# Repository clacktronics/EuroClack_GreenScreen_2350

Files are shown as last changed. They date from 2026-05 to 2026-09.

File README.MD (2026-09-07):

# EuroClack Green Screen 2350

EuroClack Green Screen 2350 is a **programmable Eurorack synthesizer module built around the Raspberry Pi RP2350B**. It combines stereo audio input/output, control-voltage (CV) and gate interfaces, a colour display, hands-on controls, microSD storage and USB connectivity.

The module provides a general-purpose platform for developing digital instruments, audio effects, sequencers and modulation tools within a Eurorack system. Application firmware defines its musical behaviour, while the audio, CV and gate interfaces connect it to the rest of the patch. The display and physical controls support interactive visual instruments and direct parameter editing.

The included firmware demonstrates a Tempest-inspired game and a double-pendulum simulation with sound. Effects processing, sampling and sequencing require their own application firmware.

## Main functions

| Function | Circuit | Purpose |
|---|---|---|
| Processing | U1, RP2350B in an 80-pin package | Runs the application, processes audio and CV, generates gates and manages the interface. |
| Program storage | U4, W25Q128JVS | External 128-Mbit / 16-MiB flash for firmware and stored data. |
| Additional memory provision | U15, labelled `SRAM` | Shares the QSPI data/clock bus with a separate chip select. The actual memory part and capacity are unspecified. |
| Two audio inputs | U6 TL072 stages and U5 PCM1808 | Condition analog signals and convert them to digital audio for the processor over I²S. |
| Two audio outputs | U2 PCM5102 and output filters | Convert the processor's I²S stream into left/right analog audio. |
| Four CV inputs | U13/U20 amplifier stages and MCU ADC inputs | Scale and offset external control voltages for measurement by the processor. |
| Four gate-sensing paths | U19/U21 LM393 comparators | Detect gate/trigger levels: two share CV inputs and two use dedicated gate jacks. |
| Four CV outputs | U3 MCP4728 and U8/U17 amplifier stages | Convert four digitally programmed values into analog control voltages. |
| Two gate outputs | U18/U22 SN74LVC1T45 | Translate processor logic into nominal 0/5-V gate signals through series output resistors. |
| Display and controls | SPI display connections, two push encoders and buttons | Provide graphical feedback, parameter editing and navigation. |
| Storage and expansion | microSD, external I²C, USB-C device and USB-A host connections | Provide hardware paths for files, peripherals and computer/device communication, subject to firmware support. |

There are **six physical CV/gate input jacks**: two CV-only, two shared CV/gate and two gate-only. The shared inputs are measured by both an ADC path and a comparator path, allowing firmware to read a control voltage and detect gate transitions from the same connection.

## How signals move through the circuit

```text
Audio inputs --> analog conditioning --> PCM1808 ADC --I²S--> RP2350B
Audio outputs <-- output filters <----- PCM5102 DAC <--I²S-- RP2350B

CV inputs ----> scaling and offset -----------------------> MCU ADCs
Gate inputs --> comparator thresholds -------------------> MCU GPIO
CV outputs <--- amplifier stages <----- MCP4728 DAC <------ MCU control
Gate outputs <- 3.3-V to 5-V translation <----------------- MCU GPIO

                     RP2350B
                        |
         Display / encoders / buttons / microSD / USB / I²C
```

The audio converters handle continuous sampled sound. The separate CV DAC and gate circuitry let firmware interact with other modular instruments: reading modulation, following clock or trigger events, and generating control signals. The analog stages adapt these signals to the processor and converters; their resistor ratios and reference voltages determine the actual voltage ranges.

## Display, controls and example firmware

The supplied sketches target an **NV3030B colour TFT at 280 × 240 pixels in landscape orientation**. The schematic provides parallel eight-pin header and FFC display connections; the fitted panel must match the driver and pinout.

- [Tempest demo](demo_scripts/nv3030b_tempest/nv3030b_tempest.ino): an encoder-controlled arcade-style game with audio output.
- [Double-pendulum demo](demo_scripts/nv3030b_pendulum/nv3030b_pendulum.ino): a visual physics simulation whose second pendulum's X/Y position drives the left/right audio channels.

The sketches demonstrate display rendering, encoder input and audio generation. USB MIDI, sample playback, sequencing and effects require additional application firmware. See [PERIPHERALS.md](PERIPHERALS.md) for GPIO assignments, converter configuration and firmware considerations.

## Power and physical construction

Power enters through the ten-pin Eurorack connector J18 using +12 V, ground and −12 V. The design includes MOSFET protection circuitry, switching and linear regulators for its intended 5-V and 3.3-V rails, and a 3.3-V reference with an inverted reference for CV conditioning. The analog amplifier stages use the bipolar rails. USB-C VBUS is unconnected, so this design is intended to be self-powered rather than powered from a computer's USB port.

The PCB contains processor, jack/control and SD-extension sections. A 40-way FFC links the processor and jack sections, carrying signals and power; separate connections serve the SD extension. Cable orientation and pin mapping are documented in [PERIPHERALS.md](PERIPHERALS.md).

## Current development status

This is a prototype design with documented electrical issues. The existing [DESIGN_REVIEW.md](DESIGN_REVIEW.md) reports power-supply faults, input-protection gaps, audio coupling/mute issues and incorrect CV output scaling. In particular, **the intended ±5-V CV range is not an established working capability**: the review calculates approximately 0–1.65 V for the current CV output stage. Read that review before assembly or power-up.

This README documents the module's architecture and application scope. Electrical findings and validation limits are recorded in the design review.

## Project files

- `EuroClack - Green_Screen_2350.kicad_pro` — open this project in KiCad.
- `EuroClack - Green_Screen_2350.kicad_sch` — current circuit schematic.
- `EuroClack - Green_Screen_2350.kicad_pcb` — PCB layout.
- [libraries/README.md](libraries/README.md) — bundled custom libraries and dependencies. The schematic uses KiCad 10 format; the PCB uses KiCad 9 format.
- [PERIPHERALS.md](PERIPHERALS.md) — detailed connections and firmware reference.
- [DESIGN_REVIEW.md](DESIGN_REVIEW.md) — existing engineering review and limitations.
- `demo_scripts/` — example display, controls and audio sketches.

The root PDF represents an older RP2040 design; use the native RP2350 KiCad schematic as the source for this revision.

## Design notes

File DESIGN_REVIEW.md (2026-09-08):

# EuroClack Green Screen 2350 — design review

Reviewed **8 September 2026**, using KiCad **10.0.6**, against the saved schematic, PCB and project settings. **Not ready for fabrication or power-up.** Five previous findings have been corrected in the schematic, but those changes have not reached the PCB. Six other finding groups remain open.

This report replaces the 7 September review. Corrected schematic complaints have been removed from the active issue list. Their implementation status is recorded below so they cannot disappear prematurely from the fabrication checklist. Design files were not edited. The previous report is preserved in [DESIGN_REVIEW.previous.md](analysis/2026-09-08_1152/DESIGN_REVIEW.previous.md).

## Changes since the previous review

| Previous finding | Current schematic evidence | Status |
|---|---|---|
| U12/U23 EN overstress | Both pin 5 EN inputs now have individual unconnected nets. TPS54302 explicitly permits floating EN. | Corrected in schematic; old 12 V connection remains on PCB |
| R4 disconnects +5 V; U12 divider gives 3.934 V | R4 removed; L2 output and R91 connect directly to +5V. R91=75k, R92=10k gives `0.596 × 8.5 = 5.066 V`. | Original fault corrected in schematic; old R4 and 56k remain on PCB |
| C9/C10 short audio input coupling | Both are now 1 µF capacitors. | Corrected in schematic; PCB values remain 0R |
| CV outputs cannot reach ±5 V | DAC-input resistors are 1.96k; negative-reference resistors 6.49k; feedback 10k. Forty current-value DC simulations agree with calculation. | Corrected nominal schematic transfer; eight PCB resistor values remain 20k |
| U2 XSMT floating | Pin 17 now connects to +3.3V, the same rail as DVDD. | Corrected in schematic; PCB still has isolated mute net |

Evidence: [current native connection inventory](analysis/2026-09-08_1152/component_connections.txt), [connectivity audit](analysis/2026-09-08_1152/connectivity_audit.json), [schematic delta](analysis/2026-09-08_1152/schematic_diff.json), and [review delta](analysis/2026-09-08_1152/review_delta.json). Floating EN is supported by [TPS54302, PDF p3](datasheets/TPS54302.pdf). The 5.066 V result resolves the old gross setpoint error; component tolerance and the required rail accuracy still need budgeting.

D3/D4 have also been added to the dedicated gate inputs. That is an attempted protection improvement, not a closed finding: see the comparator section. Library aliases have largely moved to the project-local EuroClack library. The PCB analyzer's tracked geometry/component comparison reports no changes from the prior PCB analysis; this is not a byte-for-byte equality claim.

## Active findings

| Priority | Finding | Evidence / confidence |
|---|---|---|
| Critical | PCB still implements the old supply, mute and component values; D3/D4 are missing | High: native parity and complete common-pin comparison |
| Critical | U13/U20 can overdrive the RP2350 ADC inputs | High: unchanged native nets, manufacturer limits and current DC simulation |
| Critical | U19 remains exposed to negative CV; U21 clamp current is uncontrolled | High connectivity confidence; clamp behavior depends on patch source and diode current |
| Critical | J20 reverses standard STEMMA QT power/signal order | High: native pad mapping and official connector specification |
| Critical, conditional | Q1–Q4 mapping conflicts with AO3400A/AO3401A if those are the intended parts | High conditional confidence; exact identities unresolved |
| Functional | DAC SCL/SDA are swapped relative to RP2350 hardware I2C1 | High: native nets and GPIO function definitions |
| Assembly / startup | TL072 MSOP ordering code and U15 memory remain unspecified; R3 is DNP | High documentation/population confidence; actual part compatibility unresolved |

### 1. Synchronize and route the PCB before release

The fresh DRC found **0 geometry errors, 28 warnings and 0 unconnected items**, but also **234 schematic parity issues**. Zero unrouted connections only describes the PCB's existing net assignments; it does not mean it implements the current schematic.

The following are substantive differences:

- U12.5 remains tied to +12V and U23.5 to /12V_JACK in the PCB, despite the schematic floating-enable correction. The old copper exceeds the TPS54302 EN absolute maximum of 7 V. [TPS54302, PDF pp3–4](datasheets/TPS54302.pdf)
- R4 remains a DNP 0 Ω footprint between L2 and the main +5V/output-capacitor bank. The current schematic has removed it and joined that path. Do not remove its footprint without restoring the copper connection.
- R91 remains 56k on the PCB versus 75k in the schematic. C9/C10 remain 0R versus 1u. R17/R36/R39/R42 remain 20k versus 1.96k; R13/R26/R37/R40 remain 20k versus 6.49k. These **11 value mismatches** can propagate incorrect assembly values.
- U2.17 remains on the old isolated /I2S_DAC_MUTE net instead of +3.3V.
- D3/D4 and all six pads are absent from the PCB. Their circuit also needs the protection corrections below before layout.

Native parity categorizes the 234 items as 199 field mismatches, 13 symbol/footprint mismatches, 19 net conflicts, two missing footprints and one extra footprint. Many field differences concern datasheet metadata. The 13 symbol/footprint mismatches comprise the eleven values above and two JP1/JP2 BOM-attribute differences. Five renamed nets have equivalent connected-pin sets and are not electrical opens.

Update the PCB from the corrected schematic, inspect the affected copper and population data, then rerun parity and DRC. Merely accepting renamed nets or reducing the warning count does not resolve the old EN tracks or R4 supply break. [DRC/parity report](analysis/2026-09-08_1152/drc.json)

### 2. MCU ADC input protection and range remain unresolved

U13 outputs 1/7 and U20 outputs 1/7 still directly drive U1 ADC pins 49/52/53/54. All four amplifiers run on ±12 V; there is no output-side limiting/clamping network. The input resistors are before the amplifiers and cannot protect the MCU from their output voltage.

The unchanged nominal transfer is `VADC = 1.60147 − 0.33 × VCV`:

| External CV | Nominal ADC voltage |
|---:|---:|
| −12 V | 5.561 V |
| −5 V | 3.251 V |
| 0 V | 1.601 V |
| +5 V | −0.049 V |
| +12 V | −2.359 V |

The ±12 V cases exceed the standard ADC GPIO absolute limits, −0.5 V to IOVDD+0.5 V. The +5 V case is outside the normal unipolar measurement range even though −0.049 V alone is not an absolute-maximum violation. Revise scale/offset with tolerance headroom and design output-side current limiting and clamping; include unpowered behavior and ADC settling. **High confidence: native topology, manufacturer electrical limits, and ideal DC checks.** [RP2350, electrical characteristics](datasheets/RP2350.pdf)

### 3. Comparator input protection is only partially addressed

U19 pins 3/5 still connect to the hybrid CV/gate signals through FB12/FB5. R45/R48 are on the parallel amplifier branches, not in series with the comparator inputs. Normal negative CV can therefore drive the ground-powered LM393 inputs below their −0.3 V limit. This previous finding remains unchanged for U19. [LM393, §5.1 and input-range notes](datasheets/LM393.pdf)

D4 now connects U21 pin 3 and D3 connects U21 pin 5 to dual clamps between GND and +5V. Their orientation is consistent with the BAT54SW series-diode pinout. However, the path from each dedicated gate input through the interconnect to its clamp has **no board-side series current-limiting resistor**. R95/R96 are 1 MΩ shunts, not series limiters. Clamp current therefore depends on the external source impedance; positive overvoltage also injects into +5V. A clamp is not a safe substitute for controlling that current and checking the receiving rail's ability to absorb it.

BAT54SW's forward-voltage maximum is 320 mV at 1 mA and rises at higher current, so its presence alone does not establish the LM393's −0.3 V input limit. Add a calculated series/protection arrangement on each comparator branch and evaluate clamp current, negative input behavior and powered/unpowered rails. Avoid clamping the shared bipolar measurement signal before the CV amplifier branch. D3/D4 are also absent from the PCB. **High confidence in missing current limiting; actual stress depends on the connected source.** [BAT54SW, pinning and electrical characteristics](datasheets/BAT54SW.pdf)

Comparator outputs still have no external pull-ups. Firmware pull-ups may provide operation; document startup state and rise-time requirements. Thresholds remain approximately 1.091 V and explicit hysteresis was not found.

### 4. J20 still has the wrong STEMMA QT pin order

| Pad | Current schematic and PCB | STEMMA QT SH convention |
|---|---|---|
| 1 | SCL | GND |
| 2 | SDA | V+ |
| 3 | +3.3V | SDA |
| 4 | GND | SCL |

Correct the pad mapping and verify the mating cable orientation before connecting a standard device. This finding is unchanged. **High confidence: raw/native mapping and the manufacturer's interface documentation.** [Adafruit technical specifications](https://learn.adafruit.com/introducing-adafruit-stemma-qt/technical-specs)

### 5. MOSFET identity and pin mapping remain conditional blockers

Q1/Q4 are still labelled A3400A and Q2/Q3 A3401A without explicit manufacturer MPNs. Their symbols assign 1=gate, 2=drain, 3=source. Candidate AO3400A/AO3401A parts instead use 1=gate, 2=source, 3=drain. If these are intended, the body-diode and switching topology is wrong. Resolve identity and symbol-to-pad mapping before assembly. Q1's nominal 12 V gate-source operation would also leave no margin against AO3400A's ±12 V gate rating. **High confidence conditional on the intended part.** [AO3400A, p1](datasheets/AO3400A.pdf), [AO3401A, p1](datasheets/AO3401A.pdf)

### 6. DAC hardware I²C mapping is still swapped

U1 GPIO22 goes to U3 SCL and GPIO23 to U3 SDA. RP2350's hardware I2C1 function uses GPIO22=SDA and GPIO23=SCL. Swap the connections for hardware I²C, or document and implement a software/PIO bus. The DAC's own symbol pin names are correct. **High confidence: native connectivity and GPIO function definitions.** [RP2350, GPIO22_CTRL/GPIO23_CTRL](datasheets/RP2350.pdf)

### 7. Assembly identity and boot bias remain unresolved

U6/U8/U11/U13/U17/U20 still use generic TL072 values with MSOP-8 3×3 mm footprints. The saved TI family datasheet does not establish a matching ordering code for this footprint. Specify a compatible part/package or change footprints. ±12 V operation itself is not the fault. U15 remains generic SRAM with no exact device to establish its command, voltage and package compatibility. [TL072, package information](datasheets/TL072.pdf)

R3 remains DNP in both schematic and PCB. Restore or justify the flash-CS startup bias against the [RP2350 hardware guide, flash interface](datasheets/RP2350-hardware.pdf). R22 provides a populated pull-up for the second memory. Exact passive ratings, F1 hold/trip current, connector mating and procurement suffixes remain assembly gaps; recognizable value strings do not constitute full MPN coverage.

## Power tree and analog status

| Source | Conversion / consumers | Current assessment |
|---|---|---|
| Eurorack ±12 V | Q1/Q2; six dual amplifier packages | Resolve conditional FET mapping and gate stress |
| +12 V | U12/L2 → +5V | Schematic 5.066 V nominal, direct output path and floating EN; PCB stale |
| +5 V | U14 → +3.3V MCU/digital rail | Budget total current and thermal rise |
| +12 V | U9 → +3.3VA; U16 → /3V3_DAC | Large LDO voltage drop remains |
| +12 V | U10 → +5VA audio ADC | Budget dissipation and loads |
| +5 V | U7 → 3.3 V reference; U11 → −3.3 V | Defines ADC/CV offset accuracy and startup behavior |
| /12V_JACK | U23 → /3V3_SD_SCREEN | 3.305 V nominal; schematic EN corrected, PCB stale |
| MCU 3.3 V | Internal regulator / L3 → +1V1 | Full dynamic load/inrush budget not established |

U12's output-capacitor bank is connected directly in the schematic after the R4 removal; that connection is the supply-path correction, not evidence of converter stability. U23's 100k/22k divider remains nominally correct. Both divider calculations were rerun through ideal DC servo simulations.

The corrected CV summer gives `Vjack = 5.084745763 − 0.002551020408 × code` with MCP4728 internal 2.048 V reference, gain ×1 and normal mode. Codes 33/1993/3953 give approximately +5.000562/+0.000562/−4.999438 V. Firmware must apply those DAC settings, restrict requested CV to ±5 V, and calibrate each channel. The schematic note calls for 0.1% resistor networks. This is a nominal transfer correction, not a measured precision or capacitive-load stability result. [MCP4728, reference selection](datasheets/MCP4728.pdf)

C9/C10 now restore AC isolation into the PCM1808 input network. The former 0 Ω bias-short complaint is removed for the schematic. Validate effective capacitance, low-frequency response and maximum audio input amplitude during bring-up. U2's XSMT is now high in the schematic. [PCM1808, §8.2.2.4](datasheets/PCM1808.pdf), [PCM5102, XSMT pin function](datasheets/PCM5102.pdf)

## Component and connectivity verification

Raw-file counting finds **272 non-power symbol instances, 256 physical references and 273 PCB footprints**, including mechanical/depanelization items. The native netlist contains 256 components. The inventory covers every native component's reference, value, footprint, pin function and net. All **901 common connected schematic/PCB pins** were compared, with 242 equivalent net groups; the substantive differences are listed above. D3/D4 account for six schematic pins absent from the PCB. Separate intentional NC USB VBUS pads explain another grouping difference.

The analyzer reports 94 capacitors, 73 resistors, 23 ICs, 31 connectors, four MOSFETs, four diodes, six switches, two jumpers, sixteen ferrite-category parts, and one each of crystal, other inductor and fuse. Treat this as a classification summary: the native inventory is authoritative. For example, R3 is DNP but the analyzer's summary DNP count omits it; direct inspection finds R3/R101/R102 DNP in the schematic, plus R4 on the old PCB.

Manual manufacturer-family checks and cached PDF evidence support the electrical findings above. They do not establish exact selected-part compatibility for every component. The current inventory and saved PDFs allow repeat checks, but no complete structured extraction cache or per-MPN verification coverage is claimed. The previous `analysis/deep_review.json` describes the old design and is historical only; the current [review_delta.json](analysis/2026-09-08_1152/review_delta.json) supersedes its stale supply, mute, coupling and CV-output conclusions.

## PCB, EMC and manufacturing

The panel remains approximately **109.2×110 mm, four copper layers**, with 3330 track segments, 393 vias and 14 zones. The project now permits 0.09 mm minimum track width, 0.1 mm clearance and 0.05 mm via annular width. The previous small-via concern remains: 392 vias use 0.25 mm pads and 0.15 mm drills, nominally 0.05 mm annular rings. Obtain fabricator acceptance for the actual stackup/process before release; none is specified here.

DRC with in-memory zone refill found 6 silk-edge-clearance, 4 silk-over-copper, 17 silk-overlap warnings and one dangling track. Resolve the QSPI-clock stub and artwork issues. Several checks, including library footprint matching and missing courtyards, are configured as ignored: fewer warnings do not demonstrate that every formerly reported library issue was fixed.

EMC analysis reran with **147 heuristic findings across eight checked categories**. Its aggregate score is not a compliance result. The meaningful retained risks are the jack-section reference geometry, mixed-signal interconnect returns, connector-side ESD protection and clock transitions. J21/J22 still allocate only pin 18 explicitly to ground in each 40-pin interconnect. The MCU/SD sections have inner ground zones, while the jack section relies on outer-layer ground zones. Whole-panel plane-gap estimates can overstate individual signal problems; assess actual return paths per section.

USB routed-length totals retain the previous approximate mismatches of 0.258 mm for the device link and 0.885 mm for the host link. These are trace totals, not a validated 90 Ω differential channel including FFC and packages. Connector-side USB TVS protection was not found. U1 has nine embedded plated thermal holes; do not repeat a missing-thermal-vias heuristic for it. Fiducials were not identified; provide them if required for automated assembly.

The self-powered USB-C implementation leaves VBUS unconnected and has separate 5.1k CC resistors. Firmware attach/VBUS behavior, PIO-host termination and permitted host load remain to be validated. Identify access to protected rails, +1V1, references, SWD/RUN, I²C and audio clocks for bring-up.

## Thermal and simulation results

The thermal analyzer ran but assessed **zero components** and returned SKIPPED. It is not a thermal pass. The previous first-order SPX3819 model remains applicable: 191 °C/W, 40 °C ambient, 125 °C junction ceiling, ignoring ground current. This gives approximate current ceilings of 51 mA for 12→3.3 V and 64 mA for 12→5 V. At the new 5.066 V main rail, the same model gives about 252 mA for U14's 3.3 V output. These are conditional thermal bounds, not approved load ratings. U16 at 32 mA estimates about 93 °C junction; U10 at 11 mA about 55 °C. Establish actual loads, ambient and copper cooling. [SPX3819, PDF p2](datasheets/SPX3819.pdf)

The standard SPICE runner could not find an executable simulator. The existing KiCad ngspice shared-library method was adapted to current values: **40 CV-output channel/load cases plus nine targeted DC cases passed numerical agreement checks**. These tests validate calculations, including the still-unsafe ADC transfer; they do not validate real op-amp limits, transients, regulator stability, thermal operation or damage tolerance. Scripts and results are saved in this run's [CV output checks](analysis/2026-09-08_1152/cv_output_spice/results.json) and [targeted checks](analysis/2026-09-08_1152/spice_targeted/results.json).

## Native checks, false positives and reviewer overrides

| Check | Current result |
|---|---|
| Schematic analyzer | Rerun; 171 findings before manual triage |
| PCB analyzer | Rerun with --full; compared with prior output |
| Cross-domain analyzer | Rerun; 17 findings, including the value/missing-part mismatches |
| KiCad ERC | 1 error, 65 warnings |
| KiCad DRC with parity and refill | 0 geometry errors, 28 warnings, 0 unconnected items, 234 parity items |
| Independent native connectivity | Complete common-pin comparison and missing-pad audit |
| EMC / thermal | Both rerun; heuristic EMC risks / zero thermal assessments |
| SPICE | Standard runner unavailable; 49 shared-library ideal DC checks completed |
| Prior-review delta | Schematic/PCB JSON comparison and manual reconciliation of all 11 prior finding groups |

The ERC error is **#FLG03 connected to #FLG05**, two PWR_FLAG annotations on a common net. Remove the redundant flag; it does not prove physical source contention. Warnings include off-grid endpoints, library-symbol differences, dangling wires/NC markers and alias labels. The retained I2S_DAC_MUTE label now aliases +3.3V and I2S_DAC_SCK aliases GND; clean up misleading labels as appropriate. [ERC report](analysis/2026-09-08_1152/erc.json)

Other overrides retained after checking current nets:

- The analyzer still splits GND_JACK incorrectly. Use the native netlist for ground connectivity conclusions.
- RP2350's 1.1 V core is not its GPIO voltage domain; automated 1.1 V/3.3 V interface warnings are not evidence that all digital buses need level shifters. The ADC overdrive finding instead follows the actual amplifier transfer and GPIO limits.
- REF3033 supplies ADC_AVDD through /VREF_ADC; the automated claim of no DC supply path is not accepted.
- Grounded PCM5102 SCK supports PLL/three-wire operation. PCM1808 mode pins have internal pulldowns, and U11's unused half is a terminated follower.
- Five net renamings have identical common-pin sets. J19/J28 connector-only ground heuristics require the separate power/ground connections to be considered.
- Heuristic EMC plane gaps and missing-filter lists are risks to inspect, not a count of proven emissions failures.

## Review limits and release conditions

No Gerber/drill outputs were present, so fabrication-output analysis was not applicable. No fabricator was selected. Lifecycle audit was not run because full MPN coverage is absent; the prior PCM5102 lifecycle observation was not freshly rechecked and is not presented as a current status claim. Existing PDFs and cached text support family-level checks; complete selected-part pin/package/rating verification remains unavailable for unspecified parts, especially U15 and Q1–Q4.

Not performed: switching-loop/stability, inrush, startup and fault-current simulation; full noise/THD/anti-alias/ADC-settling validation; worst-case tolerance verification; complete load budget; firmware build or memory/USB validation; measured thermal/EMC/ESD tests; new rendered schematic/layout visual review. In-memory refill was used for DRC without saving the board; analyzer copper geometry uses the saved fills.

**Release remains blocked by the stale PCB and the active electrical/assembly findings.** Correct the remaining schematic issues, synchronize and route the PCB, then rerun parity, ERC/DRC and the affected electrical checks. The five corrected schematic findings above should not be reopened as design mistakes; their remaining work is implementation in the PCB and validation of the stated operating assumptions.

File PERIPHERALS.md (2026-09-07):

# EuroClack Green Screen 2350 — peripheral / firmware reference

Basis: current RP2350 schematic and PCB, 7 September 2026. **GP numbers are MCU GPIO numbers; `U1.n` means physical QFN-80 pad n.** This is the RP2350B / 48-GPIO design, not the RP2040 design in the older root PDF. All I²C addresses below are **7-bit**. Logic is nominally 3.3 V unless stated otherwise.

Evidence: [native component connections](analysis/component_connections.txt), PCB comparison and matching [source hashes](analysis/manifest.json); linked datasheets for protocols; existing demo for the display. Pin mappings have high connectivity confidence; analog formulas are nominal calculations. Panel settings and unidentified memory remain conditional. Firmware operation has not been tested.

## Before bring-up

Resolve the power and input-protection faults in [DESIGN_REVIEW.md](DESIGN_REVIEW.md) before operating this revision: U12/U23 EN overstress; DNP R4 and the incorrect main +5 V divider; candidate MOSFET pinout mismatches; unprotected bipolar CV/comparator inputs. Audio input coupling, DAC mute and CV output scaling also need the corrections described below. Firmware cannot repair these electrical faults.

Power enters **J18: 1–2 = −12 V, 3–8 = GND, 9–10 = +12 V**, through Q1/Q2. Intended rails: U12 → +5 V; U14 → digital +3.3 V; U9 → +3.3VA for CV DAC; U10 → +5VA for audio ADC; U16 → 3V3_DAC for audio DAC; U23 → 3V3_SD_SCREEN on jack board. U7 supplies the 3.3 V ADC reference; U11 generates −3.3 V for CV offsets. These supplies have no software address or MCU enable. Y1 is annotated **12 MHz**; match the clock configuration to the fitted crystal.

## MCU pin allocation

| Peripheral / signal | GPIO → U1 physical pad | Interface / direction at MCU |
|---|---|---|
| External I²C SDA, SCL | GP4 → 1; GP5 → 2 | Hardware **I2C0**, open drain |
| CV DAC SCL, SDA | GP22 → 22; GP23 → 23 | **Software/PIO I²C** as wired |
| Audio DAC BCK, LRCK, DIN | GP6 → 3; GP7 → 4; GP8 → 6 | PIO I²S, all outputs |
| Audio ADC BCK, LRCK, DOUT | GP9 → 7; GP10 → 8; GP11 → 9 | PIO I²S: clocks out, data in |
| Audio ADC SCKI / MCLK | GP21 → 21 | CLOCK_GPOUT0 or suitable PIO clock |
| Display DC, CS, SCK, MOSI | GP12 → 11; GP13 → 12; GP14 → 13; GP15 → 14 | GPIO DC/CS; **SPI1** clock/TX |
| Display RESET, backlight | GP16 → 16; GP17 → 17 | GPIO reset; GPIO/PWM backlight |
| Gate outputs 1, 2 | GP18 → 18; GP19 → 19 | Digital outputs, active high |
| USB host D−, D+ | GP1 → 78; GP2 → 79 | PIO USB |
| USB host power control | GP24 → 25 | GPIO; intended **high = on** |
| MENU / BOOT, USER1, USER2 | GP25 → 26; GP26 → 27; GP27 → 28 | Inputs, pull-ups, active low |
| Encoder 1 switch, A, B | GP28 → 36; GP29 → 37; GP30 → 38 | Inputs with pull-ups |
| Encoder 2 switch, A, B | GP31 → 39; GP32 → 40; GP33 → 42 | Inputs with pull-ups |
| SD CLK, CMD/MOSI, DAT0/MISO | GP34 → 43; GP35 → 44; GP36 → 45 | **SPI0**, or PIO SDIO |
| SD DAT1, DAT2, DAT3/CS | GP37 → 46; GP38 → 47; GP39 → 48 | SDIO data; GP39 GPIO CS in SPI mode |
| CV inputs 1–4 | GP40 → 49; GP41 → 52; GP42 → 53; GP43 → 54 | ADC channels **0, 1, 2, 3** |
| Gate inputs 1–4 | GP44 → 55; GP45 → 56; GP46 → 57; GP47 → 58 | Digital inputs with pull-ups |
| Second QSPI memory CS | GP0 → 77 | QMI CS1n, active low |
| USB device D−, D+ | Dedicated pads 66, 67 | Native USB controller; no GP number |
| SWCLK, SWDIO, RUN | Dedicated pads 33, 34, 35 | Debug / reset; RUN active low |
| Unconnected GPIOs | GP3 → 80; GP20 → 20 | No peripheral / connector assigned |

Use an RP2350B board configuration supporting GPIOs 0–47 and its ADC mapping; do not inherit Pico 2's physical pin map, GP25 LED assumption, or 4 MiB flash size. Hardware function assignments: [RP2350 §1.2](https://datasheets.raspberrypi.com/rp2350/rp2350-datasheet.pdf).

## CV DAC — U3 MCP4728, four outputs

- **Address:** normally `0x60`; probe `0x60–0x67` for a reprogrammed/factory-selected address. At `0x60`, wire address bytes are `0xC0` write / `0xC1` read. Commands replace a numbered-register map.
- **Bus:** GP22 → U3.2 SCL; GP23 → U3.3 SDA. R105/R106 provide 10 kΩ pull-ups. Start at 100 kHz, drive low/release high and check ACKs. Hardware I2C1 would require GP22=SDA, GP23=SCL: use software/PIO or physically swap the nets.
- **Startup:** explicitly select normal operation (`PD=00`), VDD reference (`VREF=0`), gain 1. For `ch=0..3` and 12-bit `code`, send volatile Multi-Write payload `[0x40 | (ch << 1), (code >> 8) & 0x0F, code & 0xFF]`.
- **Updates:** Fast Write sends `[(code >> 8) & 0x0F, code & 0xFF]` per channel, A→D. LDAC (U3.4) is grounded: ordinary writes update sequentially. RDY/BUSY (U3.5) is NC. Use volatile writes for CV; reserve EEPROM writes for startup presets. Reprogramming the address requires unavailable LDAC transitions. [MCP4728 §§5.3–5.6](https://ww1.microchip.com/downloads/en/DeviceDoc/22187E.pdf)

| DAC channel | U3 output | Analog stage | Front-panel output |
|---|---|---|---|
| A / 0 | Pin 6 | U8A | CV1, J7 tip |
| B / 1 | Pin 7 | U8B | CV2, J8 tip |
| C / 2 | Pin 8 | U17A | CV3, J9 tip |
| D / 3 | Pin 9 | U17B | CV4, J10 tip |

**Actual nominal transfer:** `Vout = 1.65 − 0.5 × Vdac`; with VDD=3.3 V, `Vdac ≈ 3.3 × code/4096`. Increasing code decreases jack voltage. Code 0 gives about +1.65 V; 4095 gives about +0.0004 V. The present circuit cannot produce its intended ±5 V range. Internal-reference gain 2 cannot yield 4.096 V from a 3.3 V supply. Recalculate and calibrate this mapping after correcting the analog stage.

## CV inputs and gate inputs

| Front-panel input | Analog path | ADC channel / GPIO | Comparator path / GPIO |
|---|---|---|---|
| CV1, J3 tip | U13A output 1 | ADC0 / GP40 | None |
| CV2, J4 tip | U13B output 7 | ADC1 / GP41 | None |
| CV/Gate3, J5 tip | U20A output 1 | ADC2 / GP42 | U19.1 → GP46 |
| CV/Gate4, J13 tip | U20B output 7 | ADC3 / GP43 | U19.7 → GP47 |
| Gate1, J23 tip | None | None | U21.1 → GP44 |
| Gate2, J24 tip | None | None | U21.7 → GP45 |

ADC reference is U7's nominal 3.3 V on U1.59. Configure GP40–43 as analog inputs, disable pulls and select ADC0–3. For a raw 12-bit sample `r`, `Vadc ≈ r × Vref/4096`; current nominal scaling is `Vadc = 1.60147 − 0.33 × Vjack`, hence `Vjack ≈ (1.60147 − Vadc)/0.33`. Calibrate offset/gain per channel. The nominal ±5 V input range is not fully contained within the ADC range; protection and scaling must be corrected before bipolar tests.

GP44–47 are **digital gate inputs**, even though their pads also support ADC4–7. Enable pull-ups: LM393 outputs are open collector and have no external output pull-ups. Jack voltage above approximately **1.091 V reads high**; below threshold reads low. Hybrid CV/Gate3 and 4 feed both paths simultaneously. There is no explicit hysteresis; debounce/qualify slow or noisy edges. Negative voltages require the hardware protection correction. [LM393 output behaviour](https://www.ti.com/lit/ds/symlink/lm393.pdf)

## Gate outputs

| Output | MCU → level shifter | Front-panel connection |
|---|---|---|
| Gate1 | GP18 → U18.3 A; U18.4 B → R44 / FB14 | J26 tip |
| Gate2 | GP19 → U22.3 A; U22.4 B → R53 / FB13 | J27 tip |

U18/U22 are SN74LVC1T45 with DIR tied high, VCCA=3.3 V and VCCB=5 V: **non-inverting, nominal 0/5 V gates**. Initialise MCU outputs low before enabling output direction. Each jack has a 1 kΩ series output resistor; loaded high voltage is lower than 5 V. No address, enable or feedback input. [SN74LVC1T45 function table](https://www.ti.com/lit/ds/symlink/sn74lvc1t45.pdf)

## Audio — separate I²S input and output links

Neither audio converter has an I²C/SPI control address. Use PIO I²S plus DMA; pins named BCK/LRCK on the two converters are separate nets.

| Converter | Wiring | Fixed configuration / initial stream |
|---|---|---|
| U2 PCM5102 DAC | GP6 → pin13 BCK; GP7 → pin15 LRCK; GP8 → pin14 DIN | Pin16 FMT=0: I²S. Pin10 DEMP=0: off. Pin11 FLT=0: normal latency. Pin12 SCK=GND: BCK-derived PLL, no MCLK wire required |
| U5 PCM1808 ADC | GP9 → pin8 BCK; GP10 → pin7 LRCK; pin9 DOUT → GP11; GP21 → pin6 SCKI | Pin12 FMT=0: 24-bit I²S. MD1/MD0 are low via internal pull-downs (JP1/JP2 can ground them): **slave**, MCU supplies all clocks |

Start with **48 kHz LRCK, 64 BCK/frame = 3.072 MHz, 32-bit slots** on both links. ADC data are signed 24-bit MSB-first samples in the slots; observe the one-bit I²S delay and sign-extend according to the driver's packing. Supply ADC SCKI at **256×fs = 12.288 MHz**, synchronised with its LRCK/BCK. Derive clocks from a common source; nominally similar independent frequencies can cause repeated ADC resynchronisation. Discard startup/fade-in samples. [PCM1808 §§7.3–7.4](https://www.ti.com/lit/ds/symlink/pcm1808.pdf)

| Jack / numbered channel | Converter channel | Circuit note |
|---|---|---|
| Input 1: J15 tip | **U5 VINR, pin14 — right slot** | U6B → C10 → R15; gain ≈ −0.33 |
| Input 2: J2 tip | **U5 VINL, pin13 — left slot** | U6A → C9 → R16; gain ≈ −0.33 |
| Output 1: J14 tip | U2 OUTL pin6 — left slot | R1 / C1 / FB6 output filter |
| Output 2: J6 tip | U2 OUTR pin7 — right slot | R2 / C2 / FB7 output filter |

**Hardware dependencies:** C9/C10 are populated as 0 Ω, defeating ADC input coupling; restore coupling/bias before recording. U2.17 XSMT has no drive or pull-up and no MCU connection: provide a defined high level to unmute. DAC full-scale output is nominally 2.1 Vrms before load attenuation; there is no Eurorack output gain stage. [PCM5102 pin functions and output specification](https://www.ti.com/lit/ds/symlink/pcm5102.pdf)

## Display — J12 header / J30 FFC

These connectors are parallel alternatives for the same display signals. **SCL/SDA here mean SPI clock/data, not I²C.**

| Connector pin | Signal | MCU |
|---|---|---|
| 1 | GND | GND_JACK |
| 2 | Supply | 3V3_SD_SCREEN |
| 3 | SCL / SCK | GP14, SPI1 SCK |
| 4 | SDA / DIN / MOSI | GP15, SPI1 TX |
| 5 | RES | GP16, active low |
| 6 | DC | GP12, 0=command / 1=data |
| 7 | CS | GP13, active low |
| 8 | BLK | GP17, high=on in demo; PWM optional |

The schematic does not identify the panel controller; the [Tempest demo](demo_scripts/nv3030b_tempest/nv3030b_tempest.ino) targets **NV3030B, 280×240 landscape**. Reuse its complete `lcd_init()` vendor sequence for that panel: mode 0, MSB-first, RGB565 (`0x3A=0x05`), rotation `0x36=0x68`, column window 20–299, row window 0–239. Commands `0x2A/0x2B` set the window; `0x2C` writes pixels, high byte first. Reset low 5 ms, then high 50 ms; software reset waits 150 ms; sleep-out waits 120 ms. Keep backlight off until initialisation completes.

No MISO or touch-controller connection exists. Keep GP12 as DC; do not let SPI1 RX configuration take it over. The demo requests 125 MHz SPI: treat that as a demo setting, not a guaranteed panel/cable limit; start slower and validate. The net names `HSTX12...17` do not require HSTX mode. Panel identity and safe bus/backlight limits still depend on the fitted module.

## microSD — J1 and SD interconnects

Use **SPI0** initially: GP34=SCK, GP35=MOSI/CMD, GP36=MISO/DAT0, **GP39=software-controlled CS/DAT3**. GP39 is not SPI0's hardware CS function. Leave GP37/38 as inputs with pull-ups in SPI mode. No separate card-detect switch is wired; detect insertion by card responses. The same six signals support a suitable PIO 4-bit SDIO driver.

| Card signal | J1 pad | MCU-side J19 pin | Card-side J11 / J28 pin |
|---|---|---|---|
| DAT2 | 1 | 1 → GP38 | 8 |
| DAT3 / CS | 2 | 2 → GP39 | 7 |
| CMD / MOSI | 3 | 3 → GP35 | 6 |
| VDD | 4 | 4 unconnected | 5 |
| CLK | 5 | 5 → GP34 | 4 |
| VSS | 6 | 6 unconnected | 3 |
| DAT0 / MISO | 7 | 7 → GP36 | 2 |
| DAT1 | 8 | 8 → GP37 | 1 |

J19's signal mapping requires **1↔8, 2↔7, …** relative to J11/J28. Power is supplied separately via **J29.5 = 3V3_SD_SCREEN, J29.3 = GND_JACK**, matching card-side pins 5 and 3; other J29 pins are NC. Verify actual mating/cable orientation. J1 shield pad9 is NC.

Use an SD SPI library that initialises at ≤400 kHz, identifies card capacity/addressing, then raises the clock and mounts the filesystem. CS selects the card; there is no fixed device address. Provide suitable CMD/DAT pull-ups; none were found as external resistors here. [SD Association specifications](https://www.sdcard.org/downloads/pls/)

## External I²C — J20 / J31

Hardware **I2C0: GP4=SDA, GP5=SCL**, with R104/R103 10 kΩ pull-ups to +3.3 V. Start at 100 kHz; addresses depend on the attached peripheral. This bus is separate from U3's DAC bus.

| Connector | Actual pad assignment |
|---|---|
| J20, labelled STEMMA_QT | **1=SCL, 2=SDA, 3=3.3 V, 4=GND** |
| J31, three-pin | **1=SCL, 2=GND, 3=SDA**, mounting pads=GND; no power pin |

**J20 is reversed relative to standard STEMMA QT SH wiring** (1=GND, 2=V+, 3=SDA, 4=SCL). Correct the connector or use a deliberately remapped adapter before connecting a standard QT cable. [Adafruit connector specification](https://learn.adafruit.com/introducing-adafruit-stemma-qt/technical-specs)

## USB

| Port | Data path | Power / setup |
|---|---|---|
| J16 USB-C device | U1.66 DM via R43=27 Ω; U1.67 DP via R24=27 Ω → J21/J22 → J16 | Native USB device stack; connector VBUS is NC, board is self-powered. CC1/CC2 each have 5.1 kΩ to ground. There is no VBUS-sense GPIO |
| J17 USB-A host | GP1=D−, GP2=D+ → J21/J22 → J17 pins2/3 | PIO USB host stack; VBUS comes from 5V_JACK through Q3/F1; J17.4=GND |

For Pico-PIO-USB configure **`pin_dp=2`, `pinout=PIO_USB_PINOUT_DMDP`**, meaning D−=D+−1. Reserve the library's PIO state machines, DMA and timer so they do not collide with audio or SDIO. Host device addresses are assigned during enumeration. [Driver configuration](https://raw.githubusercontent.com/sekigon-gonnoc/Pico-PIO-USB/main/src/pio_usb_configuration.h), [resource requirements](https://github.com/sekigon-gonnoc/Pico-PIO-USB)

**Host power polarity:** despite the `~USBH_PWR_EN` net name, the intended Q4→Q3 circuit gives **GP24 high=VBUS on, low=off**. R100 pulls this signal toward 5 V, so reset does not guarantee power-off. Resolve the Q3/Q4 part/pad ambiguity before relying on switching; initialise low, then enable after host setup. No overcurrent-status input exists. F1's ambiguous `nSMD005 150mA` value does not establish a usable host current budget. R101/R102 host data pulldown positions are DNP; ensure termination is supplied appropriately. Device-port attach/VBUS handling also needs a deliberate self-powered implementation.

## Buttons, encoders, boot and debug

| Control | Reference | Wiring / behaviour |
|---|---|---|
| USER1 | SW1 | GP26, switch closes to ground |
| USER2 | SW2 | GP27, switch closes to ground |
| Encoder 1 | SW3 | A=GP29, B=GP30, push=GP28; common/push return=GND |
| Encoder 2 | SW4 | A=GP32, B=GP33, push=GP31; common/push return=GND |
| MENU / BOOT | SW6 | GP25; also connected through **R23=1 kΩ to flash CS** |
| RUN / reset | SW7 | U1.35 RUN directly; not a readable application GPIO |
| SWD header | J25 | **1=SWCLK, 2=GND, 3=SWDIO**; no target-power pin |

Use input pull-ups and debounce switch contacts; decode both encoder phases and determine clockwise sign mechanically. The demos call SW4 “encoder 1” and SW3 “encoder 2”, and swap each A/B naming convention; use the schematic assignments above for board-level names.

Hold SW6, press/release SW7, then release SW6 to request ROM USB boot (normal boot configuration). Do not drive GP25 as an output: it is shared with flash CS. Flash traffic can appear in GP25 reads; a reliable runtime MENU read needs a flash-idle, RAM-resident sampling routine with interrupts and the other core coordinated, then normal flash operation restored. Restore DNP R3's intended flash-CS bias as noted in the review. Use J25/SWD for recovery and debugging; no separate UART connector or user LED is fitted.

## Boot flash and second memory

| QSPI signal | U1 pad | U4 W25Q128JVS | U15 “SRAM” |
|---|---|---|---|
| CS0n | 75 | Pin1 | — |
| CS1n | GP0 / 77 | — | Pin1 |
| SCK | 71 | Pin6 | Pin6 |
| IO0 | 72 | Pin5 | Pin5 |
| IO1 | 74 | Pin2 | Pin2 |
| IO2 | 73 | Pin3 | Pin3 |
| IO3 | 70 | Pin7 | Pin7 |
| Supply / ground | QSPI I/O=3.3 V | Pin8=3.3 V, pin4=GND | Pin8=3.3 V, pin4=GND |

U4 is labelled **128 Mbit = 16 MiB** boot flash; normal QMI/XIP window starts at `0x10000000`. Set the board's flash size and boot configuration for the fitted device; use its JEDEC ID/SFDP and supported SDK flash routines instead of hard-coding an assumed suffix. The cached Winbond PDF covers a DTR variant, so it does not establish the exact fitted ordering code.

U15 shares all clock/data pins and uses GP0's QMI CS1n function. Its optional mapped window starts at **`0x11000000` after configuration**. The design specifies only “SRAM”; actual part number, capacity, commands, dummy cycles and maximum clock are unknown. Keep CS1 high and leave external RAM disabled until that part is identified and a matching QMI/PSRAM initialiser is selected. R22 supplies a 10 kΩ CS1 pull-up. Avoid changing the shared QMI bus while executing from flash. [RP2350 QMI §12.14](https://datasheets.raspberrypi.com/rp2350/rp2350-datasheet.pdf)

## Main inter-board cable — J21 ↔ J22

Required mapping is **same-number to same-number**; the cable/contact orientation must realise that mapping. MCU-side `_MICRO` and jack-side `_JACK` labels are separate native nets joined by this cable.

| Pins | Signals, in listed order |
|---|---|
| 1–4 | Audio input1, input2, output1, output2 |
| 5–8 | Hybrid CV/gate3, hybrid CV/gate4, gate input1, gate input2 |
| 9–12 | Host D+, host D−, device D+, device D− |
| 13–16 | Gate output1, gate output2, CV input1, CV input2 |
| 17–18 | +5 V, GND |
| 19–24 | Display DC, CS, SCK, MOSI, RESET, backlight |
| 25 | +12 V |
| 26–29 | MENU/BOOT, RUN, USER1, USER2 |
| 30–35 | Encoder1 push/A/B, encoder2 push/A/B |
| 36 | USB host power control |
| 37–40 | **CV output2, output4, output3, output1** |

All front-panel signal jacks use **tip=signal, sleeve=GND_JACK; ring is NC**. The 40-way link carries power and the only explicit ground connection between these sections, so correct assembly is required even for peripherals using separate data headers.

## Suggested firmware bring-up order

1. After hardware corrections, measure rails/references; establish SWD or ROM USB boot and an RP2350B build with correct crystal/flash settings.
2. Set gate outputs low, host power low, display CS high/backlight low; configure button, encoder and gate-input pull-ups. Leave unidentified U15 disabled.
3. Exercise controls/display; probe external I2C0 and the separate software/PIO DAC bus. Set explicit DAC configuration and calibrated safe output codes.
4. Start DMA audio with zero DAC samples and coherent ADC clocks; check the documented channel swap. Measure CV/gate channels with controlled inputs after protection corrections.
5. Initialise SD over SPI0, then PIO USB host. Allocate PIO/DMA centrally and recheck clocks under simultaneous display/audio/storage/USB load.

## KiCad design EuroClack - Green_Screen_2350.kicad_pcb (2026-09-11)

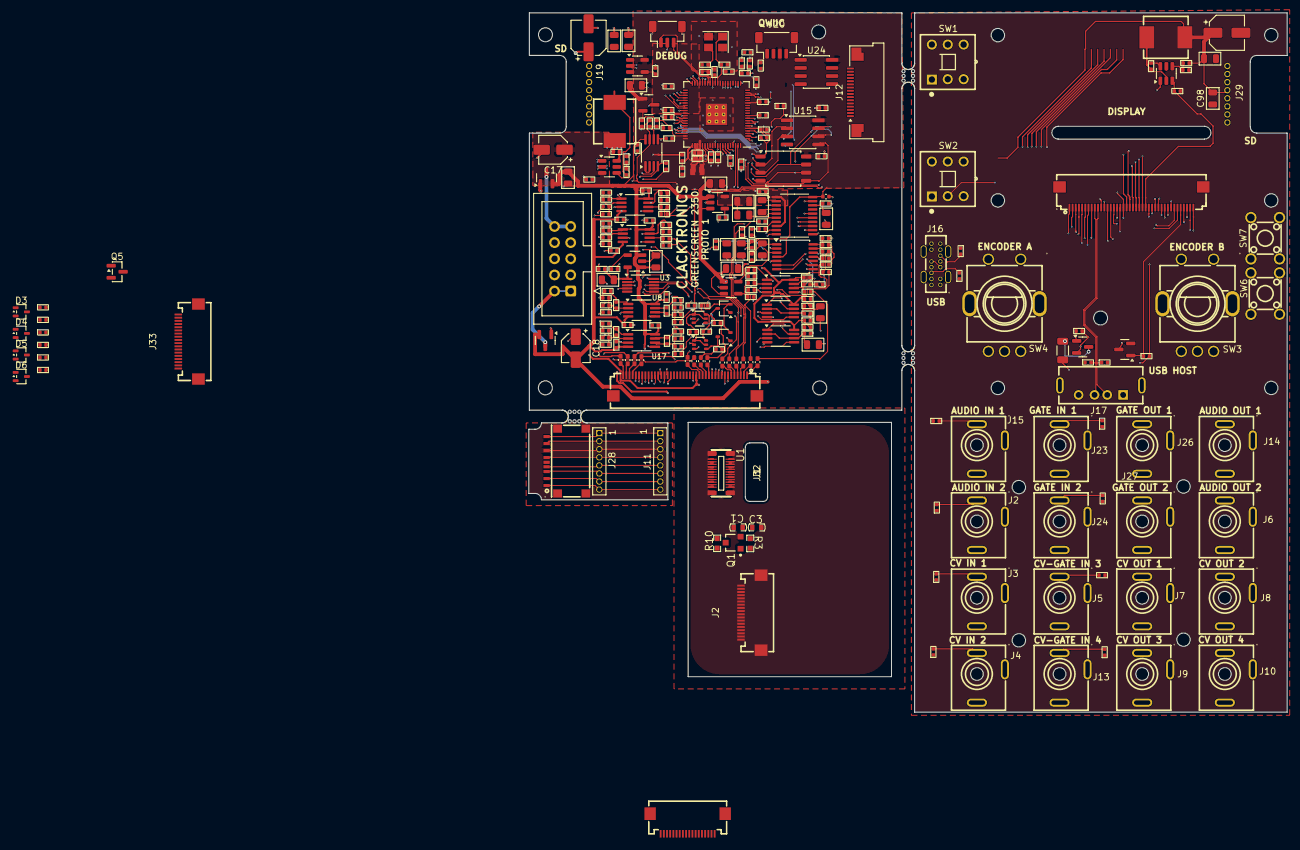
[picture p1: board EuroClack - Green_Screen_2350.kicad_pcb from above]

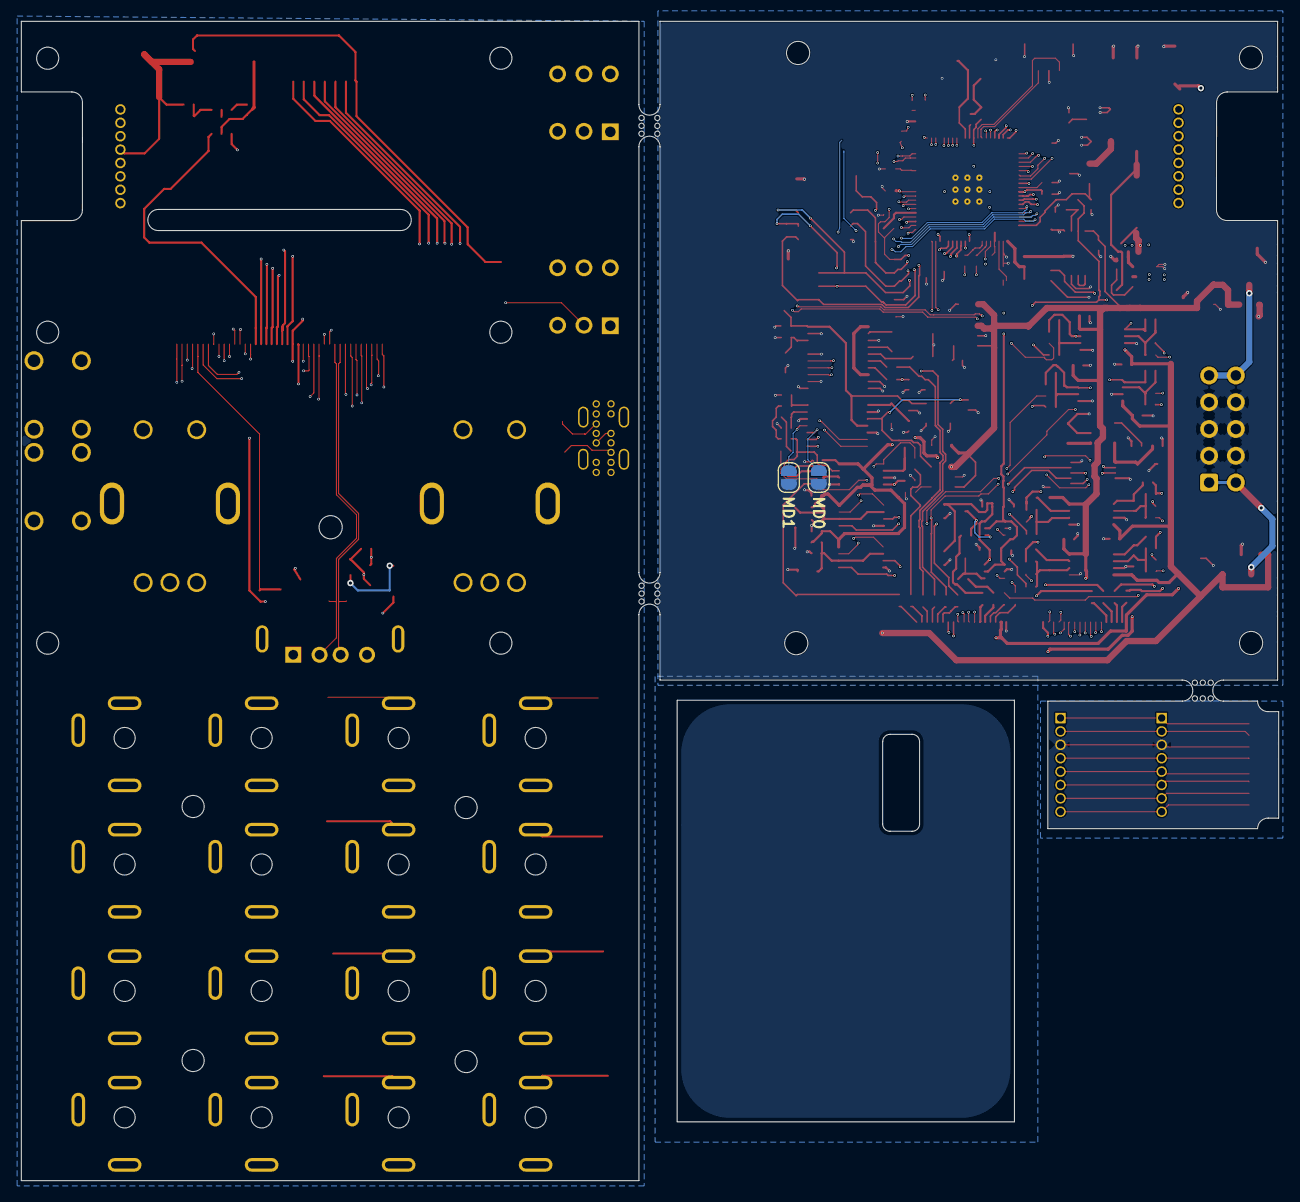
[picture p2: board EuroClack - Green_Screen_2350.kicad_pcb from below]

Board: 4 copper layers, 119.3 x 110.0 mm, 277 parts (2 on the bottom side), 228 nets.

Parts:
C1, C2, C7, C8: 2n2; C_0402_1005Metric
C1#2: Comment; C0603-1
C3, C6: 2u2; C_0805_2012Metric
C3#2: Comment; C0603-2
C4, C11, C13, C15, C21, C23, C24, C34, C45, C53, C57, C58, C60, C89, C95, C96, C98: 10uF; C_0805_2012Metric
C5, C12, C14, C16, C22, C25, C26, C37, C39, C40, C41, C42, C43, C44, C46, C47, C48, C49, C50, C51, C52, C54, C55, C56, C59, C61, C62, C63, C64, C70, C73, C74, C75, C76, C77, C78, C79, C80, C81, C82, C83, C84, C85, C86, C92, C93, C94, C97: 100n; C_0402_1005Metric
C9, C10: 1u; C_0402_1005Metric
C17, C18: 22uF; CP_Elec_4x5.4
C27, C28, C29, C30, C31, C32, C33, C67, C90, C91: 10p; C_0402_1005Metric
C38, C87: 220uF; CP_Elec_5x5.4
C65, C66: 15p; C_0402_1005Metric
C68, C69, C71, C72: 4.7u; C_0402_1005Metric
D1, D2, D3, D4, D5, D6: BAT54SW; SOT-323_SC-70
F1: nSMD005 150mA; R_1206_3216Metric
FB1, FB2, FB3, FB4, FB5, FB6, FB7, FB8, FB9, FB10, FB11, FB12, FB13, FB14: F; L_0402_1005Metric_Pad0.77x0.64mm_HandSolder
J1, J32: NV3030B QSPI; CONN-SMD_AXT524124
J1#2: C2982548; TF-SMD_TF-123-ARP9H15
J2, J3, J4, J5, J6, J7, J8, J9, J10, J13, J14, J15, J23, J24, J26, J27: Stereo Jack; AUDIO-TH_PJ-301C
J2#2, J3#2, J33: Conn_01x18; FPC-SMD_18P-P0.50_FPC-0.5-18P-HYH2.0
J11, J28: C22438074; CONN-TH_8P-P1.27_DEALON_DW127R-11-08-34
J12: Conn_01x16; Amphenol_F32Q-1A7x1-11016_1x16-1MP_P0.5mm_Horizontal
J16: C168704; USB-C-TH_TYPE-C-USB-14P
J17: USB_HOST; USB-A-TH_C42536
J18: Eurorack 10 pin socket; IDC-Header_2x05_P2.54mm_Vertical
J19, J29: C22438194; HDR-TH_8P-P1.27-H-M_1271WR-8P
J20: STEMMA_QT; JST_SH_BM04B-SRSS-TB_1x04-1MP_P1.00mm_Vertical
J21, J22: C2856837; FPC-SMD_40P-P0.50_XUNPU_FPC-05FB-40PH20
J25: SM03B-SRSS-TB; JST_SH_BM03B-SRSS-TB_1x03-1MP_P1.00mm_Vertical
JP1, JP2: SolderJumper_2_Open; SolderJumper-2_P1.3mm_Open_RoundedPad1.0x1.5mm
L2, L4: 10uH 4A; FXL0630-100-M
L3: 3.3u; L_pol_2016
Q1, Q4, Q5: AO3400A; SOT-23
Q1#2: Comment; SOT23A
Q2, Q3: AO3401A; SOT-23
R1, R2, R5, R15, R16, R23, R44, R53, R58, R59, R60, R61: 1k; R_0402_1005Metric
R3, R10#2: Comment; R0603
R3#2, R14, R18, R22, R25, R35, R38, R41, R50, R52, R92, R99, R100, R103, R104, R105, R106: 10k; R_0402_1005Metric
R6: 33; R_0402_1005Metric
R9, R29, R32, R46: 68k; R_0402_1005Metric
R10, R12, R27, R30, R33, R47: 33k; R_0402_1005Metric
R11, R28, R31, R34, R45, R48, R49, R51, R97, R108: 100k; R_0402_1005Metric
R13, R26, R37, R40: 6.49k; R_0402_1005Metric
R17, R36, R39, R42: 1.96k; R_0402_1005Metric
R24, R43: 27; R_0402_1005Metric
R54, R55, R56, R57: 220R; R_0402_1005Metric
R85, R86, R87, R88, R89, R90, R95, R96: 1M; R_0402_1005Metric
R91: 75k; R_0402_1005Metric
R93, R94: 5.1k; R_0402_1005Metric
R98: 22k; R_0402_1005Metric
R101, R102: R_0402_1005Metric
R107: 10R; R_0402_1005Metric
SW1, SW2: SW-TH_PS-8556DVA-6PN
SW3, SW4: RotaryEncoder_Switch; SW-TH_EC11XXXXXXXX
SW6, SW7: SW_Push; SW-TH_4P-L5.0-W5.0-P4.50-LS6.5
U1: Comment; TK014F1246-24P
U1#2: RP2350_80QFN; RP2350-QFN-80-1EP_10x10_P0.4mm_EP3.4x3.4mm_ThermalVias
U2: PCM5102; TSSOP-20_4.4x6.5mm_P0.65mm
U3: MCP4728; MSOP-10_3x3mm_P0.5mm
U4: W25Q128JVS; SOIC-8_5.3x5.3mm_P1.27mm
U5: PCM1808PWR; TSSOP-14_4.4x5mm_P0.65mm
U6, U8, U11, U13, U17, U20: TL072; MSOP-8_3x3mm_P0.65mm
U7: REF3033; SOT-23
U9, U14, U16: SPX3819M5-L-3-3; SOT-23-5
U10: SPX3819M5-L-5-0; SOT-23-5
U12, U23: TPS54302; SOT-23-6
U15: SRAM; SOIC-8_3.9x4.9mm_P1.27mm
U18, U22: SN74LVC1T45DCK; SOT-363_SC-70-6
U19, U21: LM393; MSOP-8_3x3mm_P0.65mm
U24: FM24CL16B; SOIC-8_3.9x4.9mm_P1.27mm
Y1: ABM8-272-T3; Crystal_SMD_3225-4Pin_3.2x2.5mm
mouse-bite-2mm-slot, mouse-bite-2mm-slot#2, mouse-bite-2mm-slot#3: VAL**; mouse-bite-2mm-slot

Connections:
3.3V: C1#2.1, C3#2.1, R3.1, U1.15, U1.17, U1.23
$1N2: Q1#2.3, R10#2.1
+1V1: C69.1, C70.1, C72.1, C73.1, L3.1, U1#2.10 (DVDD), U1#2.32 (DVDD), U1#2.51 (DVDD), U1#2.65 (VREG_FB)
+3.3V: C15.1, C16.1, C55.1, C63.1, C64.1, C68.1, C74.1, C75.1, C76.1, C77.1, C78.1, C79.1, C80.1, C81.2, C82.1, C83.1, C93.2, J1.15, J1.17, J1.23, J2#2.3, J2#2.4, J2#2.17, J3#2.1, J20.3, J32.15, J32.17, J32.23, J33.3, J33.4, J33.17, R3#2.1, R6.1, R22.1, R103.2, R104.2, R105.2, R106.2, U1#2.5 (IOVDD), U1#2.15 (IOVDD), U1#2.24 (IOVDD), U1#2.29 (IOVDD), U1#2.41 (IOVDD), U1#2.50 (IOVDD), U1#2.60 (IOVDD), U1#2.64 (VREG_VIN), U1#2.68 (USB_OTP_VDD), U1#2.69 (QSPI_IOVDD), U1#2.76 (IOVDD), U2.17 (XSMT), U2.20 (DVDD), U4.8 (VCC), U5.4 (VDD), U14.5 (OUT), U15.8 (VCC), U18.1 (VCCA), U18.5 (DIR), U22.1 (VCCA), U22.5 (DIR), U24.8 (VDD)
+3.3VA: C21.1, C22.1, U3.1 (VDD), U9.5 (OUT)
+5V: C38.1, C57.1, C58.1, C60.1, C92.1, C94.1, D1.2 (K), D2.2 (K), D3.2 (K), D4.2 (K), D5.2 (K), D6.2 (K), J21.17, L2.2, R91.2, U7.1 (IN), U14.1 (IN), U14.3 (EN), U18.6 (VCCB), U22.6 (VCCB)
+5VA: C13.1, C14.1, U5.3 (VCC), U10.5 (OUT)
+12V: C17.1, C23.1, C24.1, C39.1, C41.1, C43.1, C46.1, C47.1, C49.1, C51.1, C59.2, C62.1, C85.2, C95.2, C96.1, J21.25, Q2.2 (S), R49.2, R51.2, U6.8 (V+), U8.8 (V+), U9.1 (IN), U9.3 (EN), U10.1 (IN), U10.3 (EN), U11.8 (V+), U12.3 (VIN), U13.8 (V+), U16.1 (IN), U16.3 (EN), U17.8 (V+), U19.8 (V+), U20.8 (V+), U21.8 (V+), U23.3 (VIN)
-12V: C18.2, C40.1, C42.1, C44.1, C48.1, C50.1, C52.1, Q1.2 (S), U6.4 (V-), U8.4 (V-), U11.4 (V-), U13.4 (V-), U17.4 (V-), U20.4 (V-)
/3V3_DAC: C53.1, C54.1, U2.1 (CPVDD), U2.8 (AVDD), U16.5 (OUT)
/3V3_SD_SCREEN: C87.1, C89.1, C98.1, J12.8, J12.9, J12.16, J29.5, L4.2, R97.2
/5V_JACK: J22.17, Q3.2 (S), R99.2, R100.2
/AUDIO_IN_1_JACK: J15.T, J22.1, R86.2
/AUDIO_IN_1_MICRO: FB1.1, J21.1
/AUDIO_IN_2_JACK: J2.T, J22.2, R85.2
/AUDIO_IN_2_MICRO: FB2.1, J21.2
/AUDIO_L_IN: C10.1, C27.2, R12.2, U6.7
/AUDIO_OUT_1_JACK: J14.T, J22.3
/AUDIO_OUT_1_MICRO: FB6.2, J21.3
/AUDIO_OUT_2_JACK: J6.T, J22.4
/AUDIO_OUT_2_MICRO: FB7.2, J21.4
/AUDIO_R_IN: C9.1, C28.2, R27.2, U6.1
/CV_GATE_IN_3_JACK: J5.T, J22.5, R89.2
/CV_GATE_IN_3_MICRO: FB12.1, J21.5
/CV_GATE_IN_4_JACK: J13.T, J22.6, R90.2
/CV_GATE_IN_4_MICRO: FB5.1, J21.6
/CV_IN_1: FB3.2, R31.1
/CV_IN_1_JACK: J3.T, J22.15, R87.2
/CV_IN_1_MICRO: FB3.1, J21.15
/CV_IN_2_JACK: J4.T, J22.16, R88.2
/CV_IN_2_MICRO: FB4.1, J21.16
/CV_OUT_1: FB8.1, R18.2, R57.2
/CV_OUT_1_JACK: J7.T, J22.40
/CV_OUT_1_MICRO: FB8.2, J21.40
/CV_OUT_2: FB9.1, R35.2, R56.2
/CV_OUT_2_JACK: J8.T, J22.37
/CV_OUT_2_MICRO: FB9.2, J21.37
/CV_OUT_3: FB10.1, R38.2, R55.2
/CV_OUT_3_JACK: J9.T, J22.39
/CV_OUT_3_MICRO: FB10.2, J21.39
/CV_OUT_4: FB11.1, R41.2, R54.2
/CV_OUT_4_JACK: J10.T, J22.38
/CV_OUT_4_MICRO: FB11.2, J21.38
/ENC1_A_JACK: J22.31, SW3.A
/ENC1_A_MICRO: J21.31, U1#2.37 (GPIO29)
/ENC1_B_JACK: J22.32, SW3.B
/ENC1_B_MICRO: J21.32, U1#2.38 (GPIO30)
/ENC1_SW_JACK: J22.30, SW3.S1
/ENC1_SW_MICRO: J21.30, U1#2.36 (GPIO28)
/ENC2_A_JACK: J22.34, SW4.A
/ENC2_A_MICRO: J21.34, U1#2.40 (GPIO32)
/ENC2_B_JACK: J22.35, SW4.B
/ENC2_B_MICRO: J21.35, U1#2.42 (GPIO33)
/ENC2_SW_JACK: J22.33, SW4.S1
/ENC2_SW_MICRO: J21.33, U1#2.39 (GPIO31)
/GATE_IN_1_JACK: J22.7, J23.T, R95.2
/GATE_IN_1_MICRO: J21.7, R61.1
/GATE_IN_2_JACK: J22.8, J24.T, R96.2
/GATE_IN_2_MICRO: J21.8, R60.1
/GATE_OUT_1_JACK: J22.13, J26.T
/GATE_OUT_1_MICRO: FB14.2, J21.13
/GATE_OUT_2_JACK: J22.14, J27.T
/GATE_OUT_2_MICRO: FB13.2, J21.14
/GND_JACK: C98.2, J2.S, J3.S, J4.S, J5.S, J6.S, J7.S, J8.S, J9.S, J10.S, J13.S, J14.S, J15.S, J16.A1 (GND), J16.A12 (GND), J16.B1 (GND), J16.B12 (GND), J16.S1 (SHIELD), J17.4 (GND), J17.5 (Shield), J22.18, J23.S, J24.S, J26.S, J27.S, J29.3, Q4.2 (S), R85.1, R86.1, R87.1, R88.1, R89.1, R90.1, R93.1, R94.1, R95.1, R96.1, R101.1, R102.2, SW1.1, SW2.1, SW3.C, SW3.S2, SW4.C, SW4.S2, SW6.1, SW7.1
/HSTX12_DC: J12.1, U1#2.11 (GPIO12)
/HSTX13_CS: J12.2, U1#2.12 (GPIO13)
/HSTX14_SCK: J12.3, U1#2.13 (GPIO14)
/HSTX15_DIN: J12.4, U1#2.14 (GPIO15)
/HSTX16_RST: J12.5, U1#2.16 (GPIO16)
/HSTX17_BLK: R107.2, R108.1, U1#2.17 (GPIO17)
/I2C_DAC_SCL: J21.21, R105.1, U1#2.22 (GPIO22), U3.2 (SCL)
/I2C_DAC_SDA: J21.22, R106.1, U1#2.23 (GPIO23), U3.3 (SDA)
/I2S_ADC_BCK: U1#2.7 (GPIO9), U5.8 (BCK)
/I2S_ADC_DOUT: U1#2.9 (GPIO11), U5.9 (DOUT)
/I2S_ADC_LRCK: U1#2.8 (GPIO10), U5.7 (LRCK)
/I2S_ADC_MD0: JP2.2 (B), U5.10 (MD0)
/I2S_ADC_MD1: JP1.2 (B), U5.11 (MD1)
/I2S_ADC_SCKI: U1#2.21 (GPIO21), U5.6 (SCKI)
/I2S_DAC_BCK: U1#2.3 (GPIO6), U2.13 (BCK)
/I2S_DAC_DIN: U1#2.6 (GPIO8), U2.14 (DIN)
/I2S_DAC_LRCK: U1#2.4 (GPIO7), U2.15 (LRCK)
/LCD_CS: J1.1, J2#2.8, J3#2.7, J32.1, J33.8
/LCD_DC: J2#2.7, J3#2.8, J33.7
/LCD_RST: J1.9, J2#2.11, J32.9, J33.11
/LCD_TE: J1.14, J3#2.11, J32.14
/LEDK: J1.16, J2#2.2, J32.16, J33.2
/LED_K: J12.6, Q5.3 (D)
/MCU_CV_IN_1: C29.2, R30.2, U1#2.49 (GPIO40_ADC0), U13.1
/MCU_CV_IN_2: C30.2, R33.2, U1#2.52 (GPIO41_ADC1), U13.7
/MCU_CV_IN_3: C32.2, R10.2, U1#2.53 (GPIO42_ADC2), U20.1
/MCU_CV_IN_4: C33.2, R47.2, U1#2.54 (GPIO43_ADC3), U20.7
/MCU_GATE_IN_1: U1#2.55 (GPIO44_ADC4), U21.1
/MCU_GATE_IN_2: U1#2.56 (GPIO45_ADC5), U21.7
/MCU_GATE_IN_3: U1#2.57 (GPIO46_ADC6), U19.1
/MCU_GATE_IN_4: U1#2.58 (GPIO47_ADC7), U19.7
/MCU_GATE_OUT_1: U1#2.18 (GPIO18), U18.3 (A)
/MCU_GATE_OUT_2: U1#2.19 (GPIO19), U22.3 (A)
/QSPI_D1: J1.3, J3#2.4, J32.3
/QSPI_D2: J1.6, J3#2.5, J32.6
/QSPI_D3: J1.5, J3#2.6, J32.5
/QSPI_SCLK: U1#2.71 (QSPI_SCLK), U4.6 (CLK), U15.6 (CLK)
/QSPI_SD0: U1#2.72 (QSPI_SD0), U4.5 (DI(IO0)), U15.5 (DI(IO0))
/QSPI_SD1: U1#2.74 (QSPI_SD1), U4.2 (DO(IO1)), U15.2 (DO(IO1))
/QSPI_SD2: U1#2.73 (QSPI_SD2), U4.3 (IO2), U15.3 (IO2)
/QSPI_SD3: U1#2.70 (QSPI_SD3), U4.7 (IO3), U15.7 (IO3)
/SD_CLK: J19.5, U1#2.43 (GPIO34)
/SD_CMD: J19.3, U1#2.44 (GPIO35)
/SD_DAT0: J19.7, U1#2.45 (GPIO36)
/SD_DAT1: J19.8, U1#2.46 (GPIO37)
/SD_DAT2: J19.1, U1#2.47 (GPIO38)
/SD_DAT3: J19.2, U1#2.48 (GPIO39)
/SD_GND: J1#2.6 (VSS), J11.3, J28.3
/SPI MOSI: J1.2, J2#2.10, J3#2.3, J32.2, J33.10
/SPI_SCK: J1.4, J2#2.9, J3#2.2, J32.4, J33.9
/STEMMA_SCL: J12.12, J20.1, J21.19, R103.1, U1#2.2 (GPIO5), U24.6 (SCL)
/STEMMA_SDA: J12.13, J20.2, J21.20, R104.1, U1#2.1 (GPIO4), U24.5 (SDA)
/SWCLK: J25.1, U1#2.33 (SWCLK)
/SWD: J25.3, U1#2.34 (SWD)
/SW_RUN_JACK: J22.27, SW7.2
/SW_USR1_JACK: J22.28, SW1.2
/SW_USR2_JACK: J22.29, SW2.2
/TP_INT: J1.22, J2#2.16, J3#2.14, J12.15, J32.22, J33.16
/TP_RST: J1.21, J2#2.15, J12.14, J32.21, J33.15
/TP_SCL: J1.19, J2#2.13, J3#2.12, J32.19, J33.13
/TP_SDA: J1.20, J2#2.14, J3#2.13, J32.20, J33.14
/USB_DM_JACK: J16.A7 (D-), J16.B7 (D-), J22.12
/USB_DN: J21.12, R43.1
/USB_DP: J21.11, R24.1
/USB_DP_JACK: J16.A6 (D+), J16.B6 (D+), J22.11
/USB_HOST_DM_JACK: J17.2 (D-), J22.10, R102.1
/USB_HOST_DM_MICRO: J21.10, U1#2.78 (GPIO1)
/USB_HOST_DP_JACK: J17.3 (D+), J22.9, R101.2
/USB_HOST_DP_MICRO: J21.9, U1#2.79 (GPIO2)
/VREF_ADC: C37.1, C84.1, R25.1, U1#2.59 (ADC_AVDD), U7.2 (OUT)
/VREF_ADC_NEG: R9.1, R13.1, R14.2, R26.1, R29.1, R32.1, R37.1, R40.1, R46.1, U11.7
/VREG_AVDD: C71.1, R6.2, U1#2.61 (VREG_AVDD)
/VREG_LX: L3.2, U1#2.63 (VREG_LX)
/XIN: C65.1, U1#2.30 (XIN), Y1.1
/XOUT: R5.1, U1#2.31 (XOUT)
/~PSRAM_CS: R22.2, U1#2.77 (GPIO0), U15.1 (~CS)
/~QSPI_SS: R3#2.2, R23.1, U1#2.75 (QSPI_SS), U4.1 (~CS)
/~SW_MENU_BOOT_JACK: J22.26, SW6.2
/~SW_MENU_BOOT_MICRO: J21.26, R23.2, U1#2.26 (GPIO25)
/~SW_RUN_MICRO: J21.27, U1#2.35 (RUN)
/~SW_USR1_MICRO: J21.28, U1#2.27 (GPIO26)
/~SW_USR2_MICRO: J21.29, U1#2.28 (GPIO27)
/~USBH_PWR_EN_JACK: J22.36, Q4.1 (G), R100.1
/~USBH_PWR_EN_MICRO: J21.36, U1#2.25 (GPIO24)
BL_CTR: Q1#2.1, R3.2
GND: C1.2, C1#2.2, C2.2, C3#2.2, C4.2, C5.2, C6.2, C7.2, C8.2, C11.2, C12.2, C13.2, C14.2, C15.2, C16.2, C17.2, C18.1, C21.2, C22.2, C23.2, C24.2, C25.2, C26.2, C34.2, C37.2, C38.2, C39.2, C40.2, C41.2, C42.2, C43.2, C44.2, C45.2, C46.2, C47.2, C48.2, C49.2, C50.2, C51.2, C52.2, C53.2, C54.2, C55.2, C57.2, C58.2, C59.1, C60.2, C61.2, C62.2, C63.2, C64.2, C65.2, C66.2, C68.2, C69.2, C70.2, C71.2, C72.2, C73.2, C74.2, C75.2, C76.2, C77.2, C78.2, C79.2, C80.2, C81.1, C82.2, C83.2, C84.2, C85.1, C87.2, C89.2, C92.2, C93.1, C94.2, C95.1, C96.2, C97.2, D1.1 (A), D2.1 (A), D3.1 (A), D4.1 (A), D5.1 (A), D6.1 (A), J1.13, J1.18, J1.24, J2#2.1, J2#2.5, J2#2.6, J2#2.12, J2#2.18, J3#2.15, J12.10, J12.11, J18.3, J18.4, J18.5, J18.6, J18.7, J18.8, J20.4, J21.18, J25.2, J25.MP (MountPin), J32.13, J32.18, J32.24, J33.1, J33.5, J33.6, J33.12, J33.18, JP1.1 (A), JP2.1 (A), Q1.1 (G), Q1#2.2, Q2.1 (G), Q5.2 (S), R50.1, R52.1, R92.1, R98.1, R108.2, U1.13, U1.18, U1.24, U1.25, U1#2.62 (VREG_PGND), U1#2.81 (GND), U2.3 (CPGND), U2.9 (AGND), U2.10 (DEMP), U2.11 (FLT), U2.12 (SCK), U2.16 (FMT), U2.19 (DGND), U3.4 (~LDAC), U3.10 (VSS), U4.4 (GND), U5.2 (AGND), U5.5 (DGND), U5.12 (FMT), U6.3 (+), U6.5 (+), U7.3 (GND), U8.3 (+), U8.5 (+), U9.2 (GND), U10.2 (GND), U11.3 (+), U11.5 (+), U12.1 (GND), U13.3 (+), U13.5 (+), U14.2 (GND), U15.4 (GND), U16.2 (GND), U17.3 (+), U17.5 (+), U18.2 (GND), U19.4 (V-), U20.3 (+), U20.5 (+), U21.4 (V-), U22.2 (GND), U23.1 (GND), U24.4 (VSS), Y1.2, Y1.4
LED-: R10#2.2, U1.16
unnamed: C1.1, FB6.1, R1.2
unnamed: C2.1, FB7.1, R2.2
unnamed: C9.2, R16.1
unnamed: C10.2, R15.1
unnamed: C31.2, R57.1, U8.1
unnamed: C66.1, R5.2, Y1.3
unnamed: C67.2, R56.1, U8.7
unnamed: C90.2, R55.1, U17.1
unnamed: C91.2, R54.1, U17.7
unnamed: D1.3 (COM), R53.1, U22.4 (B)
unnamed: D2.3 (COM), R44.1, U18.4 (B)
unnamed: D3.3 (COM), R60.2, U21.5 (+)
unnamed: D4.3 (COM), R61.2, U21.3 (+)
unnamed: D5.3 (COM), R59.2, U19.5 (+)
unnamed: D6.3 (COM), R58.2, U19.3 (+)
unnamed: FB1.2, R11.1
unnamed: FB2.2, R28.1
unnamed: FB4.2, R34.1
unnamed: FB5.2, R48.1, R59.1
unnamed: FB12.2, R45.1, R58.1
unnamed: FB13.1, R53.2
unnamed: FB14.1, R44.2
unnamed: J1#2.5 (CLK), J11.4, J28.4
unnamed: J1#2.3 (CMD), J11.6, J28.6
unnamed: J1#2.7 (DAT0), J11.2, J28.2
unnamed: J1#2.8 (DAT1), J11.1, J28.1
unnamed: J1#2.1 (DAT2), J11.8, J28.8
unnamed: J1#2.2 (DAT3/CD), J11.7, J28.7
unnamed: J1#2.4 (VDD), J11.5, J28.5
unnamed: J16.A5 (CC1), R93.2
unnamed: J16.B5 (CC2), R94.2
unnamed: F1.2, J17.1 (VBUS)
unnamed: J18.1, J18.2, Q1.3 (D)
unnamed: J18.9, J18.10, Q2.3 (D)
unnamed: F1.1, Q3.3 (D)
unnamed: Q3.1 (G), Q4.3 (D), R99.1
unnamed: Q5.1 (G), R107.1
unnamed: R43.2, U1#2.66 (USB_DM)
unnamed: R24.2, U1#2.67 (USB_DP)
unnamed: C3.2, U2.4 (CAPM)
unnamed: C3.1, U2.2 (CAPP)
unnamed: C4.1, C5.1, U2.18 (LDOO)
unnamed: R1.1, U2.6 (OUTL)
unnamed: R2.1, U2.7 (OUTR)
unnamed: C6.1, U2.5 (VNEG)
unnamed: R17.1, U3.6 (VOUTA)
unnamed: R36.1, U3.7 (VOUTB)
unnamed: R39.1, U3.8 (VOUTC)
unnamed: R42.1, U3.9 (VOUTD)
unnamed: C7.1, R16.2, U5.13 (VINL)
unnamed: C8.1, R15.2, U5.14 (VINR)
unnamed: C11.1, C12.1, U5.1 (VREF)
unnamed: C28.1, R27.1, R28.2, U6.2 (-)
unnamed: C27.1, R11.2, R12.1, U6.6 (-)
unnamed: C31.1, R13.2, R17.2, R18.1, U8.2 (-)
unnamed: C67.1, R26.2, R35.1, R36.2, U8.6 (-)
unnamed: C25.1, U9.4 (BP)
unnamed: C26.1, U10.4 (BP)
unnamed: U11.1, U11.2 (-)
unnamed: R14.1, R25.2, U11.6 (-)
unnamed: C56.1, U12.6 (BOOT)
unnamed: R91.1, R92.2, U12.4 (FB)
unnamed: C56.2, L2.1, U12.2 (SW)
unnamed: C29.1, R29.2, R30.1, R31.2, U13.2 (-)
unnamed: C30.1, R32.2, R33.1, R34.2, U13.6 (-)
unnamed: C61.1, U14.4 (BP)
unnamed: C97.1, U16.4 (BP)
unnamed: C90.1, R37.2, R38.1, R39.2, U17.2 (-)
unnamed: C91.1, R40.2, R41.1, R42.2, U17.6 (-)
unnamed: C34.1, R49.1, R50.2, U19.2 (-), U19.6 (-)
unnamed: C32.1, R9.2, R10.1, R45.2, U20.2 (-)
unnamed: C33.1, R46.2, R47.1, R48.2, U20.6 (-)
unnamed: C45.1, R51.1, R52.2, U21.2 (-), U21.6 (-)
unnamed: C86.1, U23.6 (BOOT)
unnamed: R97.1, R98.2, U23.4 (FB)
unnamed: C86.2, L4.1, U23.2 (SW)
RST: U1.9, U1.21

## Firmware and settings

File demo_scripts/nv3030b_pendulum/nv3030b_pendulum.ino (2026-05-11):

/*
 * NV3030B + PCM5102 Double Pendulum
 * Landscape display, dual encoder control.
 *
 * The X and Y position of the tip of the second pendulum is sent
 * to the L and R audio channels respectively (literal chaos audio).
 *
 * Encoder 1 (GP31 SW, GP33 A, GP32 B) - SPEED:
 *   Rotate = simulation speed up/down
 *   Press  = reset speed to default (1.0x)
 *
 * Encoder 2 (GP28 SW, GP30 A, GP29 B) - PARAMETERS:
 *   Rotate = adjust currently-selected parameter
 *   Press  = cycle through parameters:
 *           L1 (length 1) → L2 (length 2) →
 *           M1 (mass 1)   → M2 (mass 2)   →
 *           GRAV (gravity)→ DAMP (damping)→ TRAIL → back
 *
 * Board: "Raspberry Pi Pico 2"
 */

#include <SPI.h>
#include <I2S.h>
#include "hardware/dma.h"
#include "hardware/spi.h"
#include "hardware/gpio.h"
#include <math.h>

// ============================================================
// Pins
// ============================================================
#define PIN_SCK  14
#define PIN_MOSI 15
#define PIN_CS   13
#define PIN_DC   12
#define PIN_RST  16
#define PIN_BLK  17

#define PIN_BCK  6
#define PIN_DIN  8

#define ENC1_SW  31
#define ENC1_A   33
#define ENC1_B   32

#define ENC2_SW  28
#define ENC2_A   30
#define ENC2_B   29

// ============================================================
// Display (landscape)
// ============================================================
#define W    280
#define H    240
#define NPIX (W * H)
#define BSIZ (NPIX * 2)

// ============================================================
// Audio
// ============================================================
#define SAMPLE_RATE  48000
#define BITS         16

// ============================================================
// Pendulum state
// ============================================================
static volatile float p_theta1 = M_PI * 0.5f;   // angle of pendulum 1 (rad)
static volatile float p_theta2 = M_PI * 0.5f;
static volatile float p_omega1 = 0.0f;          // angular velocity
static volatile float p_omega2 = 0.0f;

// Parameters (all volatile because core 1 reads them)
static volatile float p_L1   = 1.0f;            // length 1 (normalized)
static volatile float p_L2   = 1.0f;
static volatile float p_M1   = 1.0f;            // mass 1
static volatile float p_M2   = 1.0f;
static volatile float p_grav = 9.81f;
static volatile float p_damp = 0.0f;            // damping (energy loss)
static volatile float p_speed = 1.0f;           // sim speed multiplier

// Trail length parameter (number of points to remember)
#define MAX_TRAIL 200
static volatile int p_trail_len = 80;

// Reported tip position (core 1 reads, core 0 displays)
static volatile float tip_x = 0.0f;
static volatile float tip_y = 0.0f;

// ============================================================
// Trail buffer (xy positions of tip in pixels)
// ============================================================
static int16_t trail_x[MAX_TRAIL];
static int16_t trail_y[MAX_TRAIL];
static int trail_head = 0;
static int trail_count = 0;

// ============================================================
// Framebuffers
// ============================================================
static uint16_t __attribute__((aligned(4))) fb0[NPIX];
static uint16_t __attribute__((aligned(4))) fb1[NPIX];
static uint16_t* back  = fb0;
static uint16_t* front = fb1;
static int dma_ch = -1;
static bool dma_on = false;
SPISettings spiCfg(125000000, MSBFIRST, SPI_MODE0);
I2S i2s(OUTPUT);

// ============================================================
// LCD helpers
// ============================================================
static void lcmd(uint8_t c) { digitalWrite(PIN_DC,LOW); digitalWrite(PIN_CS,LOW); SPI1.transfer(c); digitalWrite(PIN_CS,HIGH); }
static void ldat(uint8_t d) { digitalWrite(PIN_DC,HIGH); digitalWrite(PIN_CS,LOW); SPI1.transfer(d); digitalWrite(PIN_CS,HIGH); }
static void lreg(uint8_t c, const uint8_t* d, int n) { lcmd(c); for(int i=0;i<n;i++) ldat(d[i]); }
#define R1(c,a)           do{uint8_t d[]={a};             lreg(c,d,1);}while(0)
#define R2(c,a,b)         do{uint8_t d[]={a,b};           lreg(c,d,2);}while(0)
#define R3(c,a,b,e)       do{uint8_t d[]={a,b,e};         lreg(c,d,3);}while(0)
#define R4(c,a,b,e,f)     do{uint8_t d[]={a,b,e,f};       lreg(c,d,4);}while(0)
#define R5(c,a,b,e,f,g)   do{uint8_t d[]={a,b,e,f,g};     lreg(c,d,5);}while(0)
#define R6(c,a,b,e,f,g,h) do{uint8_t d[]={a,b,e,f,g,h};   lreg(c,d,6);}while(0)
#define R8(c,a,b,e,f,g,h,i,j) do{uint8_t d[]={a,b,e,f,g,h,i,j};lreg(c,d,8);}while(0)

static void lcd_init() {
  digitalWrite(PIN_RST,HIGH); delay(5);
  digitalWrite(PIN_RST,LOW);  delay(5);
  digitalWrite(PIN_RST,HIGH); delay(50);
  lcmd(0x01); delay(150);
  R2(0xFD,0x06,0x08); R2(0x61,0x07,0x04);
  R3(0x62,0x00,0x44,0x45); R4(0x63,0x41,0x07,0x12,0x12);
  R1(0x64,0x37); R3(0x65,0x09,0x10,0x21);
  R3(0x66,0x09,0x10,0x21); R2(0x67,0x20,0x40);
  R4(0x68,0x90,0x4C,0x7C,0x66);
  R3(0xB1,0x0F,0x02,0x01); R1(0xB4,0x01);
  R4(0xB5,0x02,0x02,0x0A,0x14);
  R5(0xB6,0x04,0x01,0x9F,0x00,0x02);
  R1(0xDF,0x11);
  R6(0xE2,0x13,0x00,0x00,0x30,0x33,0x3F);
  R6(0xE5,0x3F,0x33,0x30,0x00,0x00,0x13);
  R2(0xE1,0x00,0x57); R2(0xE4,0x58,0x00);
  R8(0xE0,0x01,0x03,0x0D,0x0E,0x0E,0x0C,0x15,0x19);
  R8(0xE3,0x1A,0x16,0x0C,0x0F,0x0E,0x0D,0x02,0x01);
  R2(0xE6,0x00,0xFF);
  R6(0xE7,0x01,0x04,0x03,0x03,0x00,0x12);
  R3(0xE8,0x00,0x70,0x00); R1(0xEC,0x52);
  R3(0xF1,0x01,0x01,0x02); R4(0xF6,0x09,0x10,0x00,0x00);
  R2(0xFD,0xFA,0xFC);
  R1(0x35,0x00); R1(0x3A,0x05);
  R1(0x36,0x68);  // 90° CW
  lcmd(0x21); lcmd(0x11); delay(120);
  lcmd(0x29); delay(50);
  digitalWrite(PIN_BLK, HIGH);
}

// ============================================================
// DMA
// ============================================================
static void dma_setup() {
  dma_ch = dma_claim_unused_channel(true);
  dma_channel_config cfg = dma_channel_get_default_config(dma_ch);
  channel_config_set_transfer_data_size(&cfg, DMA_SIZE_8);
  channel_config_set_dreq(&cfg, spi_get_dreq(spi1, true));
  channel_config_set_read_increment(&cfg, true);
  channel_config_set_write_increment(&cfg, false);
  dma_channel_configure(dma_ch, &cfg, &spi_get_hw(spi1)->dr, nullptr, BSIZ, false);
}

static void dma_wait() {
  if (!dma_on) return;
  dma_channel_wait_for_finish_blocking(dma_ch);
  while (spi_is_busy(spi1)) tight_loop_contents();
  digitalWrite(PIN_CS, HIGH);
  dma_on = false;
}

static void swap_and_send() {
  dma_wait();
  uint16_t* t = back; back = front; front = t;
  digitalWrite(PIN_CS, LOW);
  digitalWrite(PIN_DC, LOW); SPI1.transfer(0x2A);
  digitalWrite(PIN_DC, HIGH);
  SPI1.transfer(0x00); SPI1.transfer(0x14);
  SPI1.transfer(0x01); SPI1.transfer(0x2B);
  digitalWrite(PIN_DC, LOW); SPI1.transfer(0x2B);
  digitalWrite(PIN_DC, HIGH);
  SPI1.transfer(0x00); SPI1.transfer(0x00);
  SPI1.transfer(0x00); SPI1.transfer(0xEF);
  digitalWrite(PIN_DC, LOW); SPI1.transfer(0x2C);
  digitalWrite(PIN_DC, HIGH);
  dma_channel_set_read_addr(dma_ch, front, false);
  dma_channel_set_trans_count(dma_ch, BSIZ, true);
  dma_on = true;
}

// ============================================================
// Drawing
// ============================================================
static inline uint16_t rgb(uint8_t r, uint8_t g, uint8_t b) {
  uint16_t c = ((r&0xF8)<<8)|((g&0xFC)<<3)|(b>>3);
  return (c>>8)|(c<<8);
}

static inline void px(int x, int y, uint16_t c) {
  if ((unsigned)x < W && (unsigned)y < H) back[y * W + x] = c;
}

static void drawrect(int x0, int y0, int w, int h, uint16_t c) {
  for (int y = max(0,y0); y < min(H,y0+h); y++)
    for (int x = max(0,x0); x < min(W,x0+w); x++)
      back[y * W + x] = c;
}

static void hline(int x0, int x1, int y, uint16_t c) {
  if (y < 0 || y >= H) return;
  x0 = max(0, x0); x1 = min(W-1, x1);
  for (int x = x0; x <= x1; x++) back[y * W + x] = c;
}

static void thick_line(int x0, int y0, int x1, int y1, uint16_t c, int thick) {
  int dx = abs(x1 - x0), sx = x0 < x1 ? 1 : -1;
  int dy = -abs(y1 - y0), sy = y0 < y1 ? 1 : -1;
  int err = dx + dy, half = thick / 2;
  while (true) {
    for (int t = -half; t <= half; t++) {
      int py = y0 + t;
      if ((unsigned)x0 < W && (unsigned)py < H) back[py * W + x0] = c;
      // Also expand horizontally for thicker diagonals
      int px2 = x0 + t;
      if ((unsigned)px2 < W && (unsigned)y0 < H) back[y0 * W + px2] = c;
    }
    if (x0 == x1 && y0 == y1) break;
    int e2 = 2 * err;
    if (e2 >= dy) { err += dy; x0 += sx; }
    if (e2 <= dx) { err += dx; y0 += sy; }
  }
}

static void fill_circle(int cx, int cy, int r, uint16_t c) {
  int r2 = r * r;
  int y0 = max(0, cy - r), y1 = min(H - 1, cy + r);
  for (int y = y0; y <= y1; y++) {
    int dy = y - cy;
    int dx = (int)sqrtf((float)(r2 - dy * dy));
    int x0 = max(0, cx - dx), x1 = min(W - 1, cx + dx);
    uint16_t* row = &back[y * W + x0];
    for (int x = x0; x <= x1; x++) *row++ = c;
  }
}

// --- Font ---
static const uint8_t font[][5] = {
  {0x3E,0x51,0x49,0x45,0x3E},{0x00,0x42,0x7F,0x40,0x00}, // 0 1
  {0x42,0x61,0x51,0x49,0x46},{0x21,0x41,0x45,0x4B,0x31}, // 2 3
  {0x18,0x14,0x12,0x7F,0x10},{0x27,0x45,0x45,0x45,0x39}, // 4 5
  {0x3C,0x4A,0x49,0x49,0x30},{0x01,0x71,0x09,0x05,0x03}, // 6 7
  {0x36,0x49,0x49,0x49,0x36},{0x06,0x49,0x49,0x29,0x1E}, // 8 9
  {0x7E,0x11,0x11,0x11,0x7E},{0x7F,0x49,0x49,0x49,0x36}, // A B
  {0x3E,0x41,0x41,0x41,0x22},{0x7F,0x41,0x41,0x22,0x1C}, // C D
  {0x7F,0x49,0x49,0x49,0x41},{0x7F,0x09,0x09,0x09,0x01}, // E F
  {0x3E,0x41,0x49,0x49,0x7A},{0x7F,0x08,0x08,0x08,0x7F}, // G H
  {0x00,0x41,0x7F,0x41,0x00},{0x20,0x40,0x41,0x3F,0x01}, // I J
  {0x7F,0x08,0x14,0x22,0x41},{0x7F,0x40,0x40,0x40,0x40}, // K L
  {0x7F,0x02,0x0C,0x02,0x7F},{0x7F,0x04,0x08,0x10,0x7F}, // M N
  {0x3E,0x41,0x41,0x41,0x3E},{0x7F,0x09,0x09,0x09,0x06}, // O P
  {0x3E,0x41,0x51,0x21,0x5E},{0x7F,0x09,0x19,0x29,0x46}, // Q R
  {0x46,0x49,0x49,0x49,0x31},{0x01,0x01,0x7F,0x01,0x01}, // S T
  {0x3F,0x40,0x40,0x40,0x3F},{0x1F,0x20,0x40,0x20,0x1F}, // U V
  {0x3F,0x40,0x38,0x40,0x3F},{0x63,0x14,0x08,0x14,0x63}, // W X
  {0x07,0x08,0x70,0x08,0x07},{0x61,0x51,0x49,0x45,0x43}, // Y Z
  {0x00,0x00,0x00,0x00,0x00},{0x00,0x60,0x60,0x00,0x00}, // sp .
};

static void text(int x, int y, const char* s, uint16_t c, int sc) {
  while (*s) {
    int idx = -1;
    if (*s>='0' && *s<='9') idx = *s-'0';
    else if (*s>='A' && *s<='Z') idx = *s-'A'+10;
    else if (*s>='a' && *s<='z') idx = *s-'a'+10;
    else if (*s==' ') idx = 36;
    else if (*s=='.') idx = 37;
    if (idx >= 0) {
      const uint8_t* g = font[idx];
      for (int col=0; col<5; col++)
        for (int row=0; row<7; row++)
          if (g[col] & (1<<row))
            drawrect(x+col*sc, y+row*sc, sc, sc, c);
    }
    x += 6*sc;
    s++;
  }
}

// ============================================================
// Encoder (parallel arrays, GPIO SDK)
// ============================================================
static int      enc_pin_a[2]      = { ENC1_A, ENC2_A };
static int      enc_pin_b[2]      = { ENC1_B, ENC2_B };
static int      enc_pin_sw[2]     = { ENC1_SW, ENC2_SW };
static uint8_t  enc_last_ab[2]    = { 0, 0 };
static bool     enc_sw_last[2]    = { true, true };
static uint32_t enc_sw_debounce[2]= { 0, 0 };

static void enc_init(int idx) {
  gpio_init(enc_pin_a[idx]);
  gpio_set_dir(enc_pin_a[idx], GPIO_IN);
  gpio_pull_up(enc_pin_a[idx]);
  gpio_init(enc_pin_b[idx]);
  gpio_set_dir(enc_pin_b[idx], GPIO_IN);
  gpio_pull_up(enc_pin_b[idx]);
  gpio_init(enc_pin_sw[idx]);
  gpio_set_dir(enc_pin_sw[idx], GPIO_IN);
  gpio_pull_up(enc_pin_sw[idx]);
  enc_last_ab[idx] = (gpio_get(enc_pin_a[idx]) << 1) | gpio_get(enc_pin_b[idx]);
  enc_sw_last[idx] = true;
  enc_sw_debounce[idx] = 0;
}

static int enc_read(int idx) {
  uint8_t a = gpio_get(enc_pin_a[idx]);
  uint8_t b = gpio_get(enc_pin_b[idx]);
  uint8_t ab = (a << 1) | b;
  int dir = 0;
  if (ab != enc_last_ab[idx]) {
    uint8_t transition = (enc_last_ab[idx] << 2) | ab;
    switch (transition) {
      case 0b0001: case 0b0111: case 0b1110: case 0b1000: dir =  1; break;
      case 0b0010: case 0b1011: case 0b1101: case 0b0100: dir = -1; break;
    }
    enc_last_ab[idx] = ab;
  }
  return dir;
}

static bool enc_button(int idx) {
  bool state = gpio_get(enc_pin_sw[idx]);
  uint32_t now = millis();
  if (state != enc_sw_last[idx] && (now - enc_sw_debounce[idx]) > 50) {
    enc_sw_debounce[idx] = now;
    enc_sw_last[idx] = state;
    if (!state) return true;
  }
  return false;
}

// ============================================================
// Parameters
// ============================================================
enum Param { P_L1=0, P_L2, P_M1, P_M2, P_GRAV, P_DAMP, P_TRAIL, P_COUNT };
static const char* param_names[] = { "L1", "L2", "M1", "M2", "GRAV", "DAMP", "TRAIL" };
static int current_param = P_L1;

static void adjust_param(int dir) {
  switch (current_param) {
    case P_L1:    p_L1 = constrain(p_L1 + dir * 0.05f, 0.2f, 2.0f); break;
    case P_L2:    p_L2 = constrain(p_L2 + dir * 0.05f, 0.2f, 2.0f); break;
    case P_M1:    p_M1 = constrain(p_M1 + dir * 0.1f, 0.1f, 5.0f); break;
    case P_M2:    p_M2 = constrain(p_M2 + dir * 0.1f, 0.1f, 5.0f); break;
    case P_GRAV:  p_grav = constrain(p_grav + dir * 0.5f, 0.0f, 30.0f); break;
    case P_DAMP:  p_damp = constrain(p_damp + dir * 0.005f, 0.0f, 0.5f); break;
    case P_TRAIL: p_trail_len = constrain(p_trail_len + dir * 5, 0, MAX_TRAIL); break;
  }
}

static float get_param_value(int p) {
  switch (p) {
    case P_L1:    return p_L1;
    case P_L2:    return p_L2;
    case P_M1:    return p_M1;
    case P_M2:    return p_M2;
    case P_GRAV:  return p_grav;
    case P_DAMP:  return p_damp;
    case P_TRAIL: return (float)p_trail_len;
  }
  return 0;
}

// ============================================================
// Double pendulum physics (RK4 integration on core 1)
// State is (t1, t2, w1, w2) passed as separate args to avoid
// Arduino preprocessor issues with struct types in prototypes.
// ============================================================

// Returns derivatives via output pointers
static void derivs(float t1, float t2, float w1, float w2,
                   float* dt1, float* dt2, float* dw1, float* dw2) {
  float L1 = p_L1, L2 = p_L2, m1 = p_M1, m2 = p_M2, g = p_grav;
  float damp = p_damp;

  float dt = t1 - t2;
  float sin_dt = sinf(dt);
  float cos_dt = cosf(dt);
  float sin_t1 = sinf(t1);

  float den = 2.0f * m1 + m2 - m2 * cosf(2.0f * dt);
  if (fabsf(den) < 1e-6f) den = 1e-6f;

  float num1 = -g * (2.0f * m1 + m2) * sin_t1
               - m2 * g * sinf(t1 - 2.0f * t2)
               - 2.0f * sin_dt * m2 * (w2 * w2 * L2 + w1 * w1 * L1 * cos_dt);
  float a1 = num1 / (L1 * den);

  float num2 = 2.0f * sin_dt
               * (w1 * w1 * L1 * (m1 + m2)
                  + g * (m1 + m2) * cosf(t1)
                  + w2 * w2 * L2 * m2 * cos_dt);
  float a2 = num2 / (L2 * den);

  *dt1 = w1;
  *dt2 = w2;
  *dw1 = a1 - damp * w1;
  *dw2 = a2 - damp * w2;
}

static void rk4_step(float* t1, float* t2, float* w1, float* w2, float h) {
  float k1_t1, k1_t2, k1_w1, k1_w2;
  float k2_t1, k2_t2, k2_w1, k2_w2;
  float k3_t1, k3_t2, k3_w1, k3_w2;
  float k4_t1, k4_t2, k4_w1, k4_w2;

  derivs(*t1, *t2, *w1, *w2, &k1_t1, &k1_t2, &k1_w1, &k1_w2);

  derivs(*t1 + 0.5f*h*k1_t1, *t2 + 0.5f*h*k1_t2,
         *w1 + 0.5f*h*k1_w1, *w2 + 0.5f*h*k1_w2,
         &k2_t1, &k2_t2, &k2_w1, &k2_w2);

  derivs(*t1 + 0.5f*h*k2_t1, *t2 + 0.5f*h*k2_t2,
         *w1 + 0.5f*h*k2_w1, *w2 + 0.5f*h*k2_w2,
         &k3_t1, &k3_t2, &k3_w1, &k3_w2);

  derivs(*t1 + h*k3_t1, *t2 + h*k3_t2,
         *w1 + h*k3_w1, *w2 + h*k3_w2,
         &k4_t1, &k4_t2, &k4_w1, &k4_w2);

  *t1 += (h/6.0f) * (k1_t1 + 2*k2_t1 + 2*k3_t1 + k4_t1);
  *t2 += (h/6.0f) * (k1_t2 + 2*k2_t2 + 2*k3_t2 + k4_t2);
  *w1 += (h/6.0f) * (k1_w1 + 2*k2_w1 + 2*k3_w1 + k4_w1);
  *w2 += (h/6.0f) * (k1_w2 + 2*k2_w2 + 2*k3_w2 + k4_w2);
}

// ============================================================
// Colors (all green theme)
// ============================================================
static uint16_t col_bg, col_grid, col_dim, col_text;
static uint16_t col_arm1, col_arm2, col_bob1, col_bob2, col_pivot;
static uint16_t col_trail, col_trail_dim, col_param, col_value;
static uint16_t col_speed_norm, col_speed_alt;

// ============================================================
// FPS
// ============================================================
static float fps = 0;
static uint32_t fps_count = 0;
static uint32_t fps_timer = 0;

static void fps_tick() {
  fps_count++;
  uint32_t now = millis();
  if (now - fps_timer >= 500) {
    fps = fps_count * 1000.0f / (now - fps_timer);
    fps_count = 0;
    fps_timer = now;
  }
}

// ============================================================
// Pendulum render
// ============================================================
#define PIVOT_X (W / 2)
#define PIVOT_Y (H / 2 - 10)
#define PX_PER_UNIT 45.0f   // pixel scale per unit length

static void draw_pendulum() {
  memset(back, 0, BSIZ);

  // Read state atomically-ish (worst case is one frame of tearing, fine for visuals)
  float t1 = p_theta1, t2 = p_theta2;
  float L1 = p_L1, L2 = p_L2;
  float M1 = p_M1, M2 = p_M2;

  // Compute joint positions
  int x0 = PIVOT_X;
  int y0 = PIVOT_Y;
  int x1 = x0 + (int)(L1 * PX_PER_UNIT * sinf(t1));
  int y1 = y0 + (int)(L1 * PX_PER_UNIT * cosf(t1));
  int x2 = x1 + (int)(L2 * PX_PER_UNIT * sinf(t2));
  int y2 = y1 + (int)(L2 * PX_PER_UNIT * cosf(t2));

  // Add tip to trail
  trail_x[trail_head] = x2;
  trail_y[trail_head] = y2;
  trail_head = (trail_head + 1) % MAX_TRAIL;
  if (trail_count < MAX_TRAIL) trail_count++;

  // Draw trail (oldest = darkest, newest = brightest)
  int trail_to_draw = min((int)p_trail_len, trail_count);
  for (int i = 0; i < trail_to_draw - 1; i++) {
    int idx_a = (trail_head - trail_to_draw + i + MAX_TRAIL) % MAX_TRAIL;
    int idx_b = (trail_head - trail_to_draw + i + 1 + MAX_TRAIL) % MAX_TRAIL;
    // Brightness ramp from dim to bright
    float fade = (float)i / (float)trail_to_draw;
    uint8_t g = (uint8_t)(40 + fade * 180);
    uint8_t r = (uint8_t)(fade * 30);
    uint16_t c = rgb(r, g, r);
    int ax = trail_x[idx_a], ay = trail_y[idx_a];
    int bx = trail_x[idx_b], by = trail_y[idx_b];
    thick_line(ax, ay, bx, by, c, 1);
  }

  // Draw arms (thick lines)
  thick_line(x0, y0, x1, y1, col_arm1, 2);
  thick_line(x1, y1, x2, y2, col_arm2, 2);

  // Pivot
  fill_circle(x0, y0, 4, col_pivot);

  // Bobs (size scaled by mass)
  int r1 = (int)(4 + sqrtf(M1) * 3);
  int r2 = (int)(4 + sqrtf(M2) * 3);
  fill_circle(x1, y1, r1, col_bob1);
  fill_circle(x2, y2, r2, col_bob2);
}

// ============================================================
// Draw HUD overlay
// ============================================================
static void draw_hud() {
  // --- Title ---
  text(20, 8, "DOUBLE PENDULUM", col_text, 2);

  // --- Speed indicator (top right) ---
  char sbuf[16];
  float speed = p_speed;
  if (fabsf(speed - 1.0f) < 0.01f) {
    snprintf(sbuf, sizeof(sbuf), "%.2fX", (double)speed);
    text(W - 60, 10, sbuf, col_speed_norm, 1);
  } else {
    snprintf(sbuf, sizeof(sbuf), "%.2fX", (double)speed);
    text(W - 60, 10, sbuf, col_speed_alt, 1);
  }

  // --- Parameter panel (left side) ---
  int px_y = 30;
  for (int i = 0; i < P_COUNT; i++) {
    uint16_t name_col = (i == current_param) ? col_param : col_dim;
    uint16_t val_col  = (i == current_param) ? col_value : col_dim;

    // Name
    text(4, px_y + i * 11, param_names[i], name_col, 1);

    // Value
    char vbuf[12];
    float v = get_param_value(i);
    if (i == P_TRAIL) {
      snprintf(vbuf, sizeof(vbuf), "%d", (int)v);
    } else if (i == P_GRAV) {
      snprintf(vbuf, sizeof(vbuf), "%.1f", (double)v);
    } else if (i == P_DAMP) {
      snprintf(vbuf, sizeof(vbuf), "%.3f", (double)v);
    } else {
      snprintf(vbuf, sizeof(vbuf), "%.2f", (double)v);
    }
    text(34, px_y + i * 11, vbuf, val_col, 1);

    // Selector indicator (>)
    if (i == current_param) {
      text(0, px_y + i * 11, ".", col_param, 1);  // small marker
    }
  }

  // --- Bottom info ---
  text(4, H - 20, "ENC1 SPEED", col_dim, 1);
  text(W - 100, H - 20, "ENC2 PARAM", col_dim, 1);

  // FPS center bottom
  char fbuf[16];
  snprintf(fbuf, sizeof(fbuf), "%d.%d FPS", (int)fps, ((int)(fps*10))%10);
  int flen = strlen(fbuf);
  text((W - flen * 6) / 2, H - 10, fbuf, col_dim, 1);
}

// ============================================================
// CORE 1: Audio + physics
// ============================================================
// Run physics here too, at audio rate. Each sample we step the
// physics by dt = 1/SAMPLE_RATE * speed. The X/Y position of the
// tip are normalized and sent to L/R audio channels.

void setup1() {}
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
void loop() {
  // --- Encoder 1: Speed ---
  int dir1 = enc_read(0);
  if (dir1) {
    p_speed = constrain(p_speed * powf(1.06f, dir1), 0.05f, 8.0f);
  }
  if (enc_button(0)) {
    p_speed = 1.0f;  // reset to default
  }

  // --- Encoder 2: Parameter ---
  int dir2 = enc_read(1);
  if (dir2) {
    adjust_param(dir2);
  }
  if (enc_button(1)) {
    current_param = (current_param + 1) % P_COUNT;
  }

  // Render
  draw_pendulum();
  draw_hud();
  swap_and_send();
  fps_tick();
}

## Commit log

2025-04-22 First dump of files
    [EuroClack - Green_Screen_2350.kicad_pcb, EuroClack - Green_Screen_2350.kicad_sch]
2025-04-22 work on connectors layout
    [EuroClack - Green_Screen_2350.kicad_pcb, EuroClack - Green_Screen_2350.kicad_sch, EuroClack - Green_Screen_2350.step]
2026-01-05 Added ground pour to panel and asjusted nets to suit
    [EuroClack - Green_Screen_2350.kicad_pcb, EuroClack - Green_Screen_2350.kicad_sch]
2026-01-06 little bits
    [EuroClack - Green_Screen_2350.kicad_pcb, EuroClack - Green_Screen_2350.kicad_sch]
2026-01-19 Updated pinouts to work better
    [EuroClack - Green_Screen_2350.kicad_sch]
2026-02-16 misc changes
    [EuroClack - Green_Screen_2350.kicad_pcb]
2026-02-24 Panel routing
    [EuroClack - Green_Screen_2350.kicad_pcb]
2026-03-03 Physical prototypes tested, needed shifting
    [EuroClack - Green_Screen_2350.kicad_pcb]
2026-03-06 More changes
    [EuroClack - Green_Screen_2350.kicad_pcb, EuroClack - Green_Screen_2350.kicad_sch, SW-TH_PS-8556DVA-6PN.step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]
2026-04-16 Prototype pushed
    [EuroClack - Green_Screen_2350.kicad_pcb, EuroClack - Green_Screen_2350.kicad_sch]
2026-05-11 Errors list
    [EuroClack - Green_Screen_2350.kicad_sch]
2026-09-07 Major re-orgainisation and LLM design reveiw
    [EuroClack - Green_Screen_2350.kicad_pcb, EuroClack - Green_Screen_2350.kicad_sch, EuroClack - Green_Screen_2350.step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]
2026-09-08 Further design review
    [EuroClack - Green_Screen_2350.kicad_sch]
2026-09-08 Tweaks for next prototype
    [EuroClack - Green_Screen_2350.kicad_sch]
2026-09-11 Starting to re-arrange board
    [EuroClack - Green_Screen_2350.kicad_pcb, EuroClack - Green_Screen_2350.kicad_sch]
